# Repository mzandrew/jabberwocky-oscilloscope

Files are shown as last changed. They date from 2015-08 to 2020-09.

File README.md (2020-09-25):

# jabberwocky-oscilloscope
an open-source & open-hardware oscilloscope

Jabberwocky is an acronym for Just Another Big Bandwidth Event Recorder With Oscilloscope Capabilities.

It is a combination of hardware designs and software that uses an ASIC switched-capacitor-array ADC to make a handheld, battery/usb powered, 2 channel oscilloscope with an OLED display.

Development on the oscilloscope was started in January, 2008. A design was finalized and a board was fabricated in May of that year.

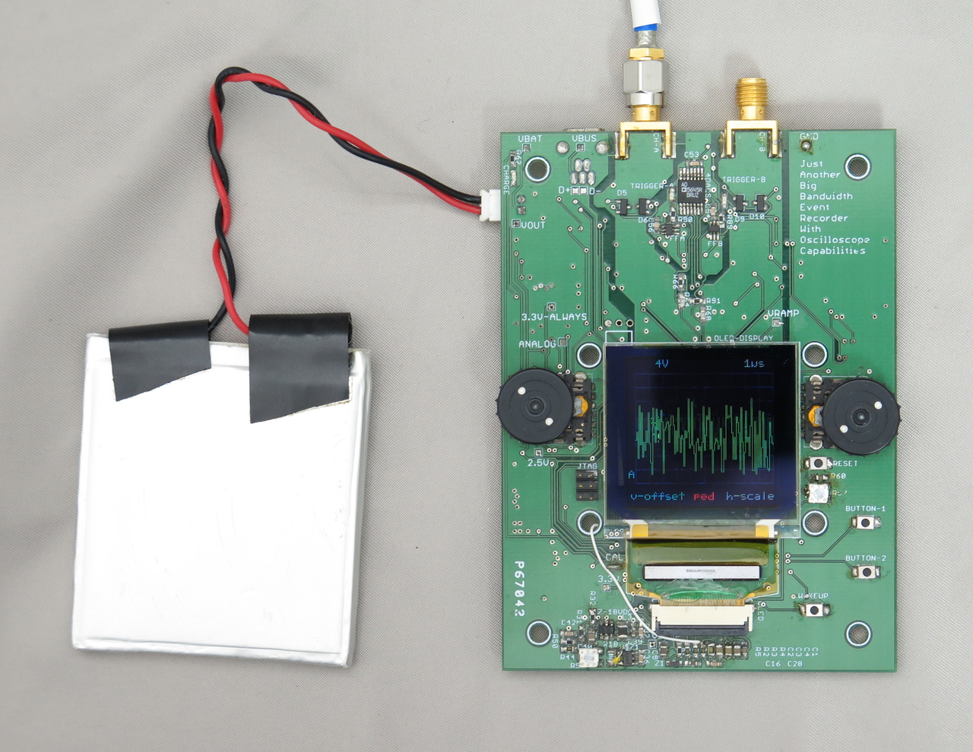
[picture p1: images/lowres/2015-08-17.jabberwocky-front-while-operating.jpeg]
while operating


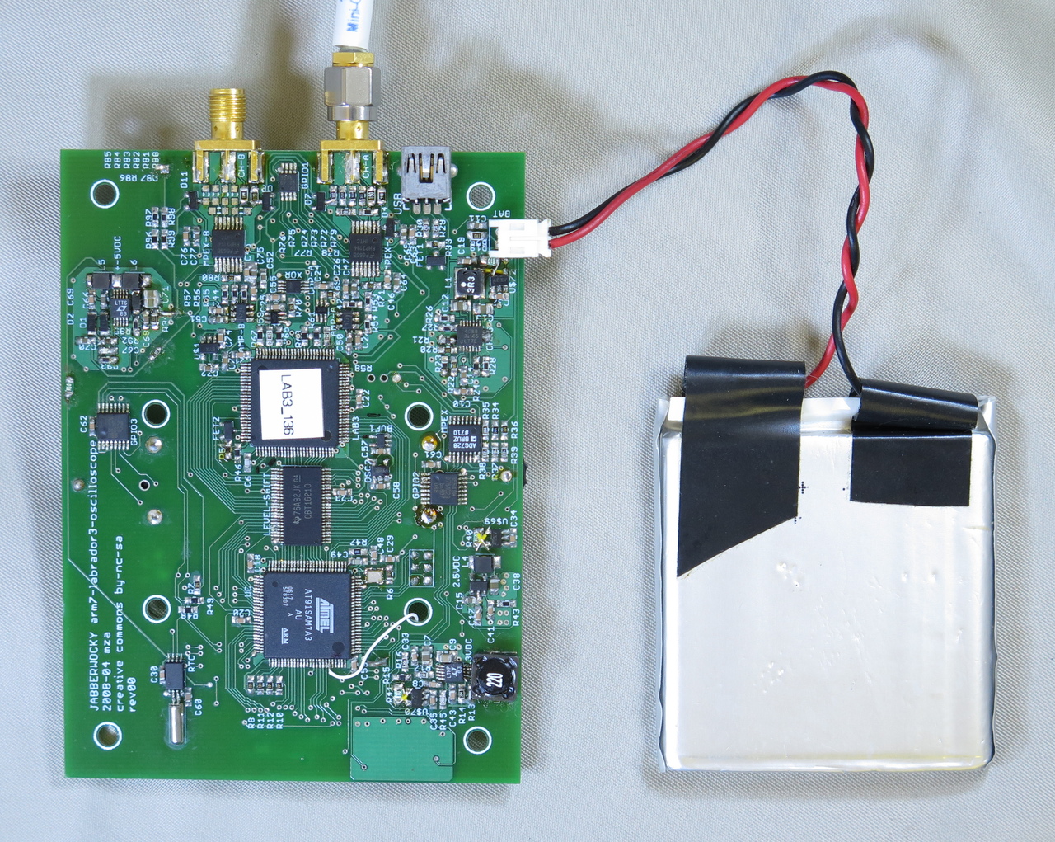
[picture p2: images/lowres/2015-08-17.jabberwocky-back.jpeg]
printed-circuit-board


# overview

The oscilloscope is battery (rechargable LiPoly) or usb powered, has 2 channels of input (DC coupled only), has a 128×124 pixel full-color OLED display. It supports (slightly) advanced triggering or an optional trigger-delay.

The input impedance of this scope is 1MOhm. The analog bandwidth is unknown at this point (and will be until the project is nearly complete). The lab3 can sample billions of times per second, but this oscilloscope will probably only be useful at a much much lower sampling speed. This is due to the choice of input amplifier and multiplexer: The multiplexer has a bandwidth of about 700MHz as does the voltage-feedback operational amplifier.

# files

[PCB schmatic](jabberwocky-PCB-eagle/jabberwocky.schematic.pdf)

[PCB layout](jabberwocky-PCB-eagle/jabberwocky.layout.pdf)

[PCB gerber files](jabberwocky-PCB-eagle/arm7-oscilloscope-gerbers.zip)

# notes

Automatically exported from code.google.com/p/jabberwocky-oscilloscope

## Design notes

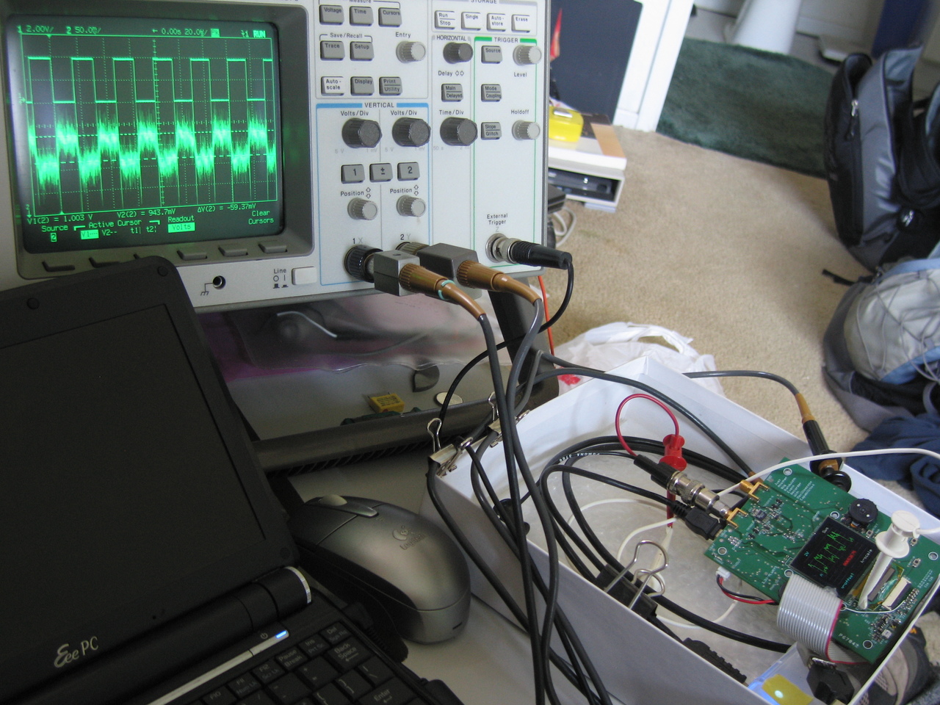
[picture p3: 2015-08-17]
images/lowres/2009-06-07.18_14_17.canon-s70.00828.first-light.second-jabberwocky-scope-trace.jpeg

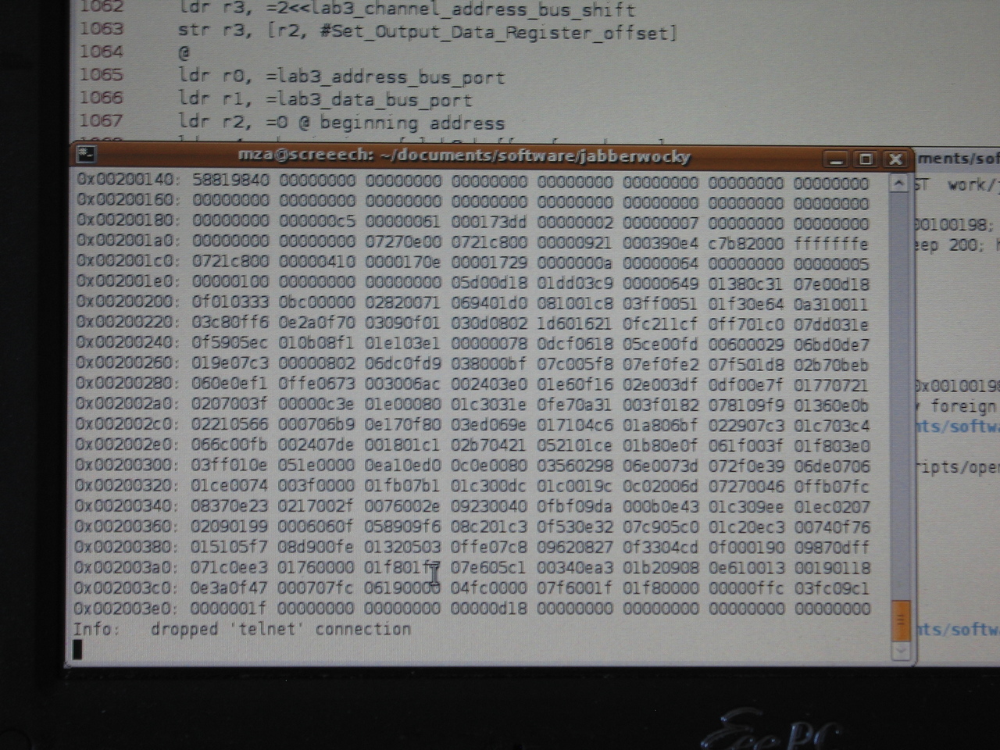
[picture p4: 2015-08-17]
images/lowres/2009-05-30.16_30_52.canon-s70.00823.first-light.first-jabberwocky-lab3-data-hexdump.jpeg

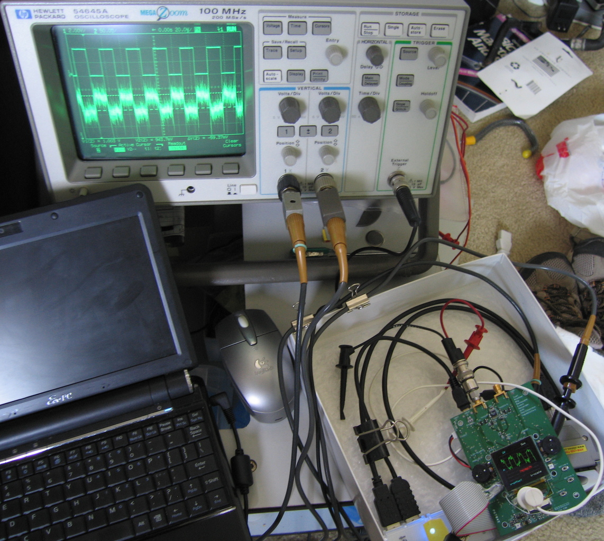
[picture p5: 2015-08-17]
images/lowres/2009-06-07.18_14_04.canon-s70.00827.first-light.first-jabberwocky-scope-trace.jpeg

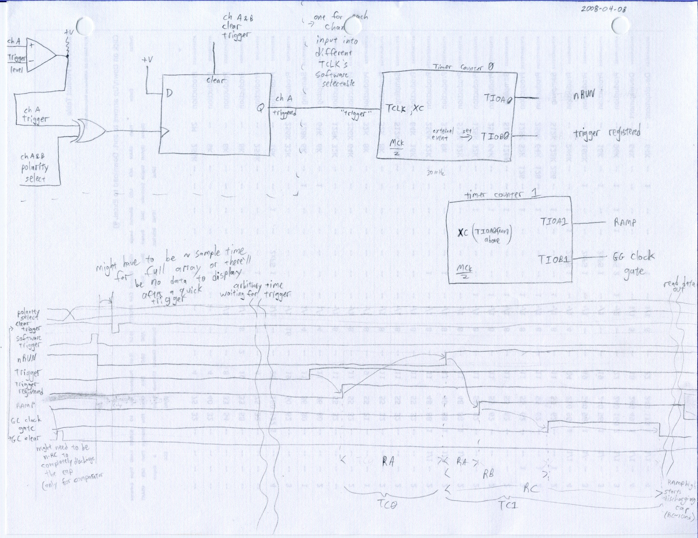
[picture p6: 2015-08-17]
images/jabberwocky-trigger-delay-timing-diagram.jpeg

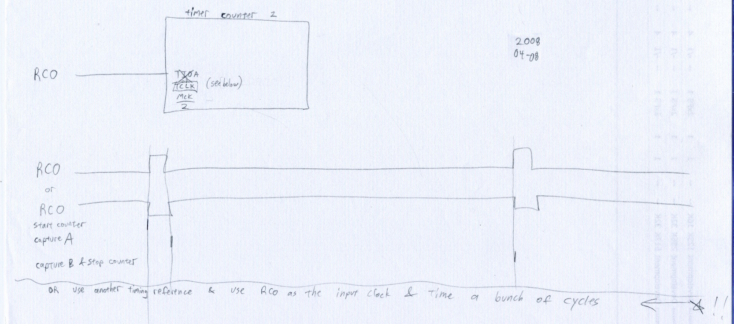
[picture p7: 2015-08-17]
images/jabberwocky-rco-timing-diagram.jpeg

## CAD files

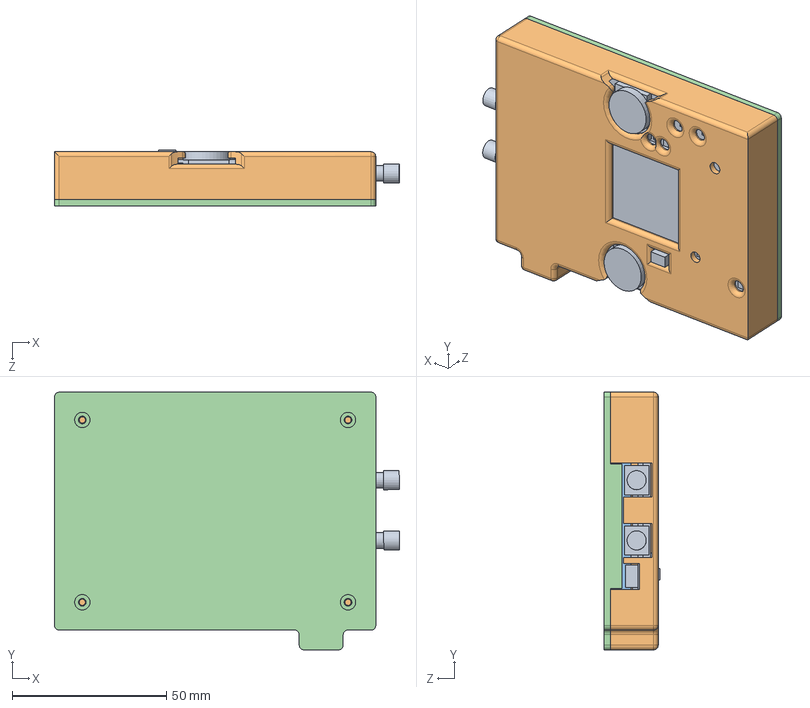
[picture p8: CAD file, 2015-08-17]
jabberwocky-PCB-eagle/jabberwocky.SLDASM
111.7 x 83.4 x 18.0 mm
jabberwocky-PCB
jabberwocky-case-OLED-side
battery
jabberwocky-case-IC-side

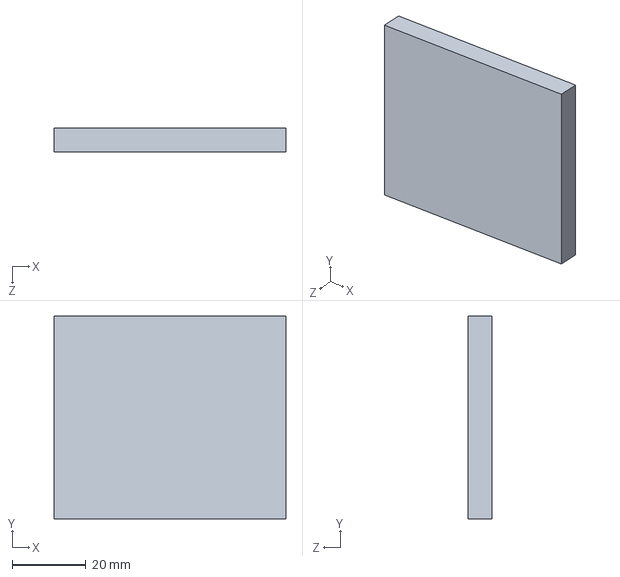
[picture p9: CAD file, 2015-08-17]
jabberwocky-PCB-eagle/battery.SLDPRT
63.0 x 55.0 x 6.50 mm

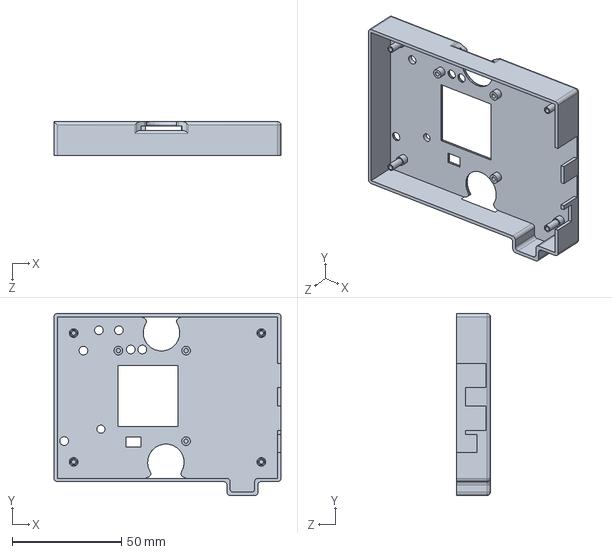
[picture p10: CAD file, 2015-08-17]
jabberwocky-PCB-eagle/jabberwocky-case-OLED-side.sldprt
104.0 x 83.4 x 15.5 mm

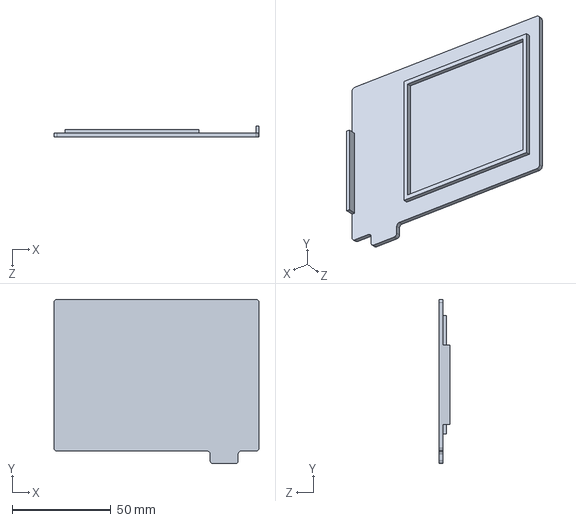
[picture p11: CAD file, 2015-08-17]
jabberwocky-PCB-eagle/jabberwocky-case-IC-side.sldprt
104.0 x 83.4 x 5.75 mm

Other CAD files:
jabberwocky-PCB-eagle/jabberwocky-case-IC-side.STL
jabberwocky-PCB-eagle/jabberwocky-case-OLED-side.STL

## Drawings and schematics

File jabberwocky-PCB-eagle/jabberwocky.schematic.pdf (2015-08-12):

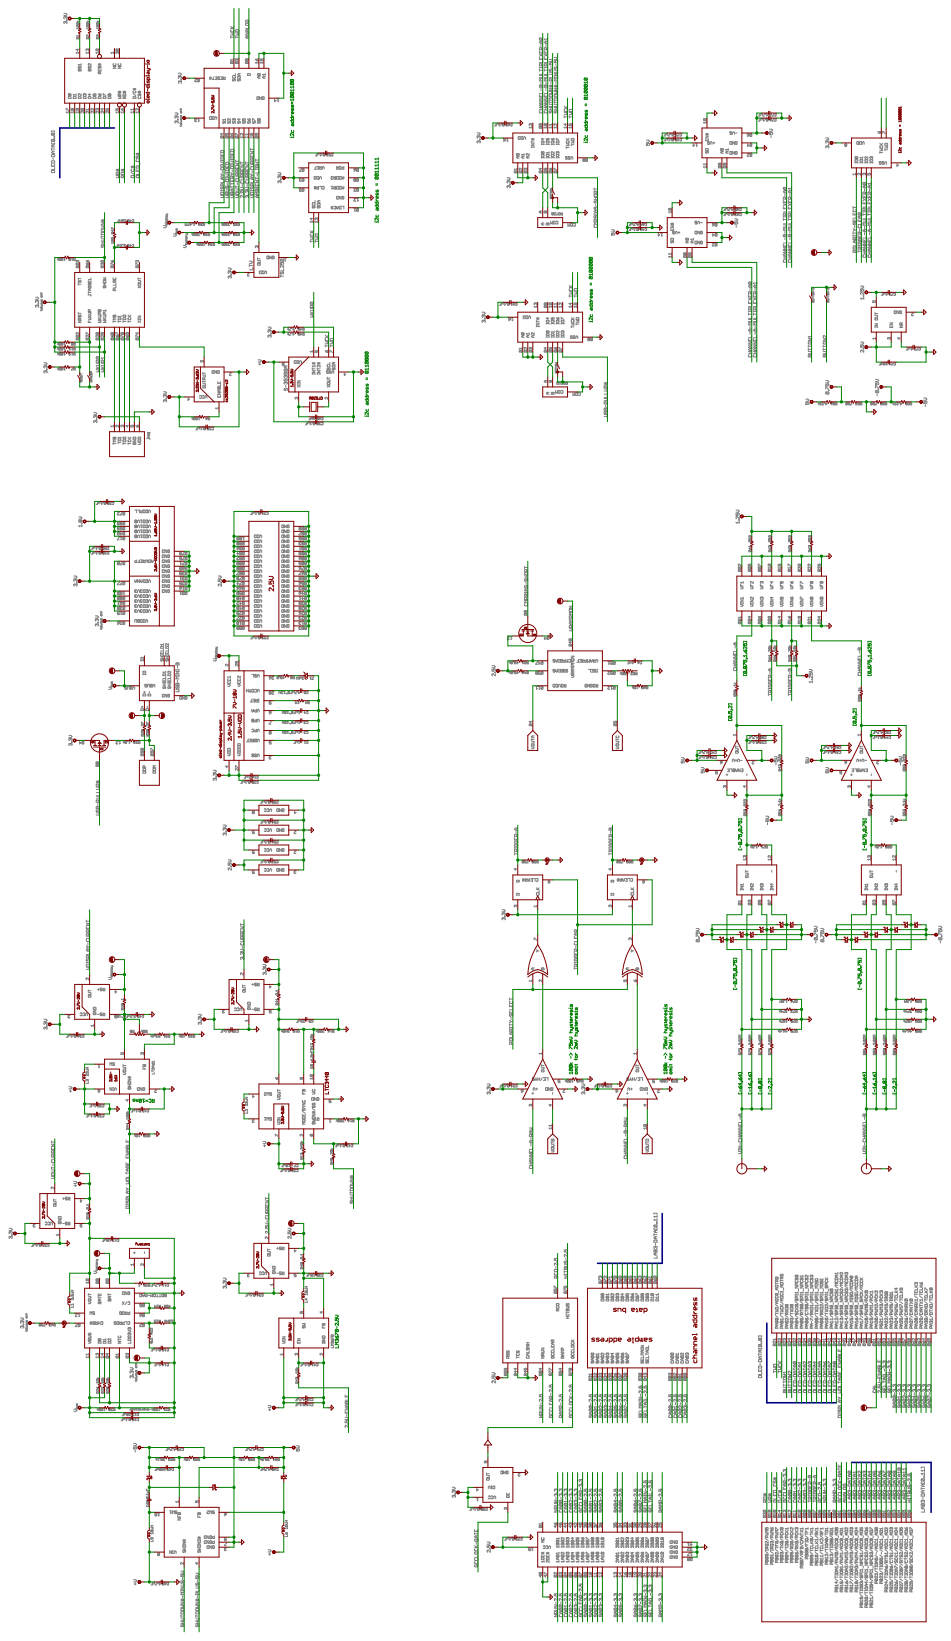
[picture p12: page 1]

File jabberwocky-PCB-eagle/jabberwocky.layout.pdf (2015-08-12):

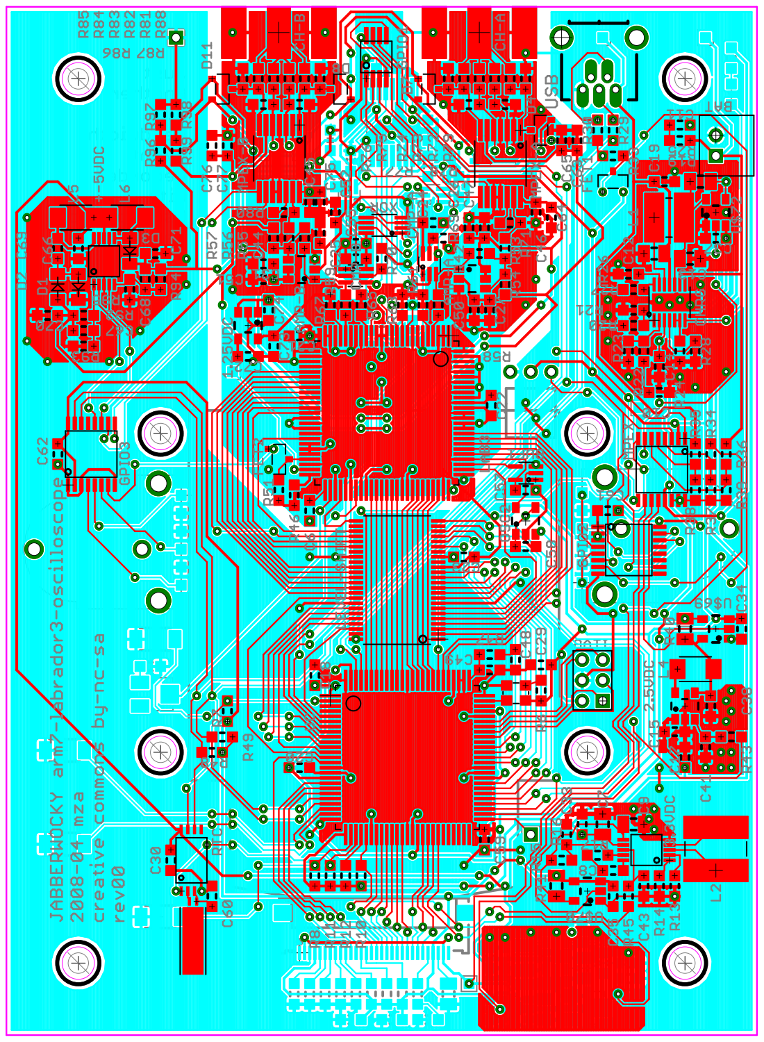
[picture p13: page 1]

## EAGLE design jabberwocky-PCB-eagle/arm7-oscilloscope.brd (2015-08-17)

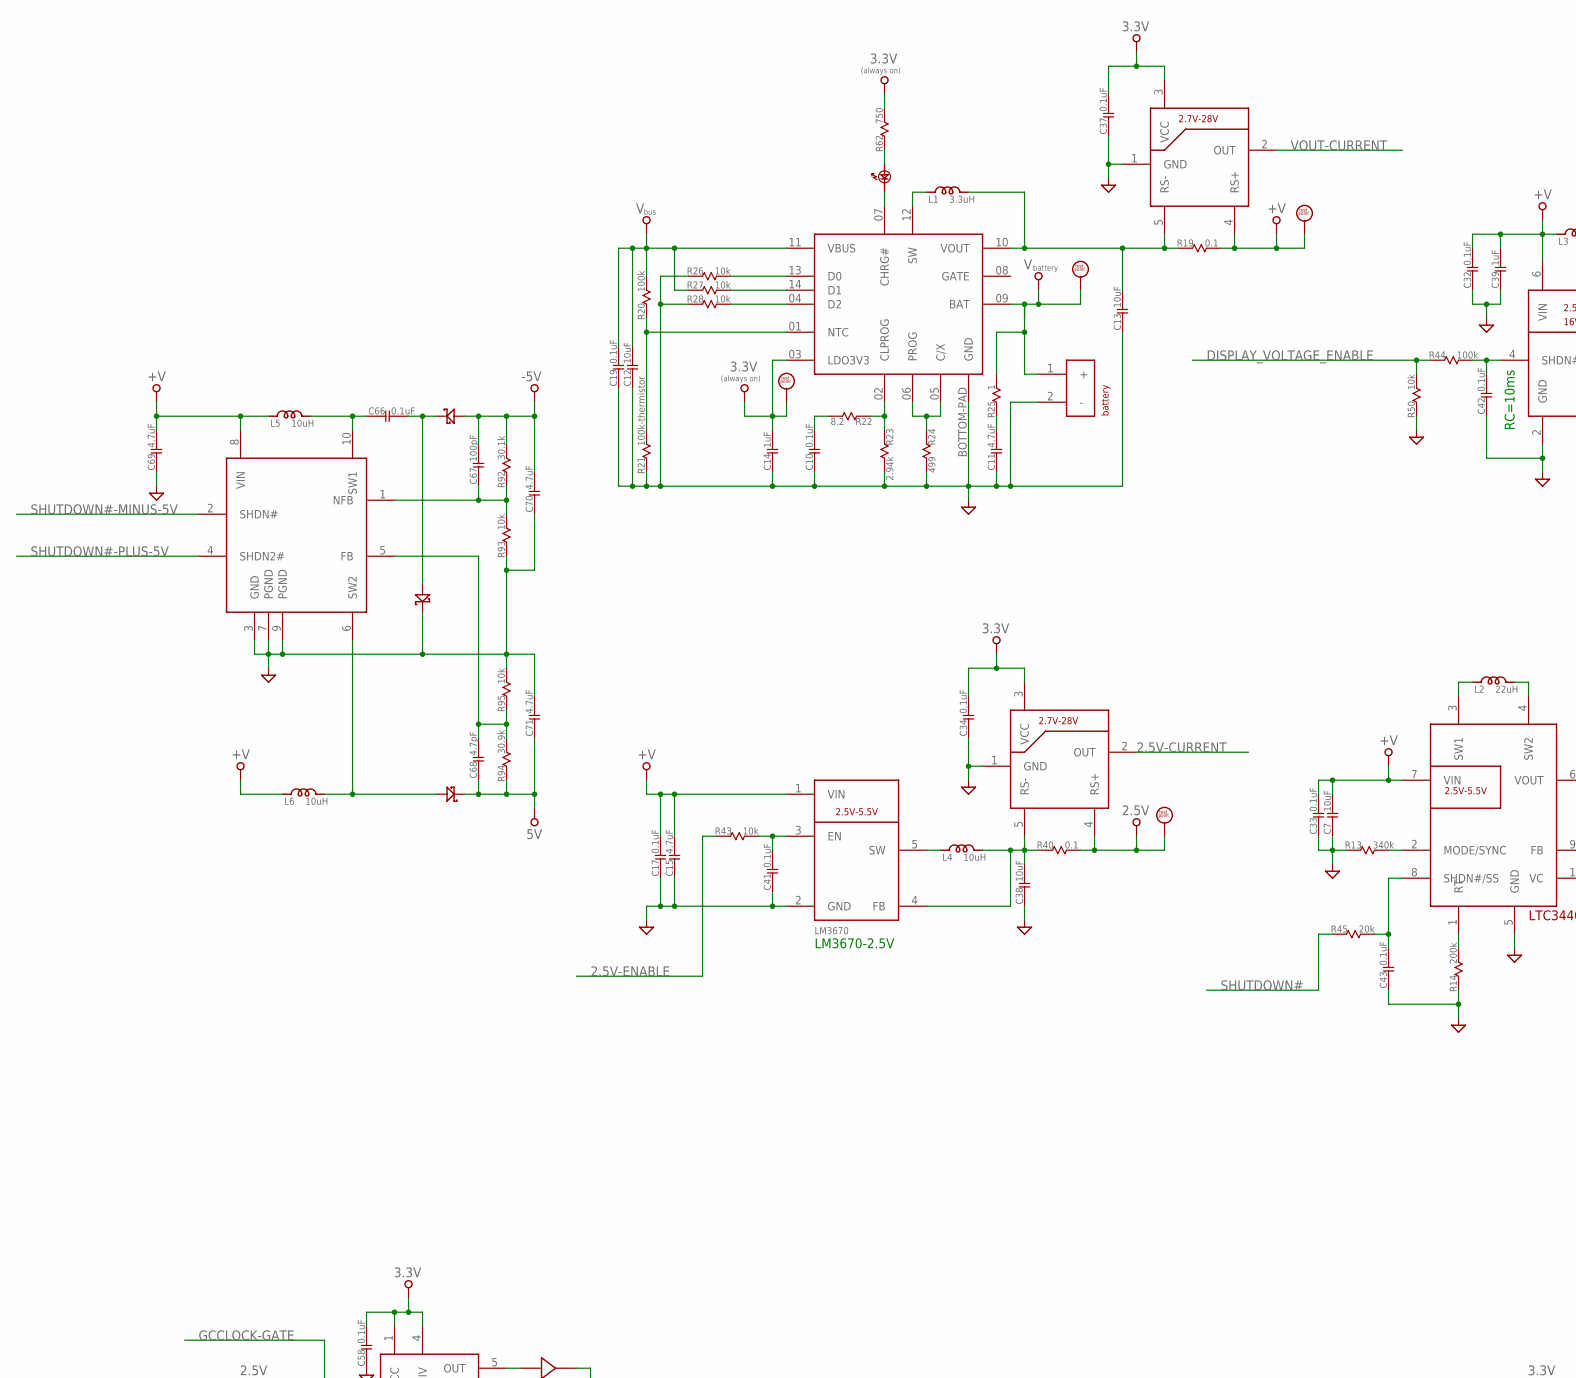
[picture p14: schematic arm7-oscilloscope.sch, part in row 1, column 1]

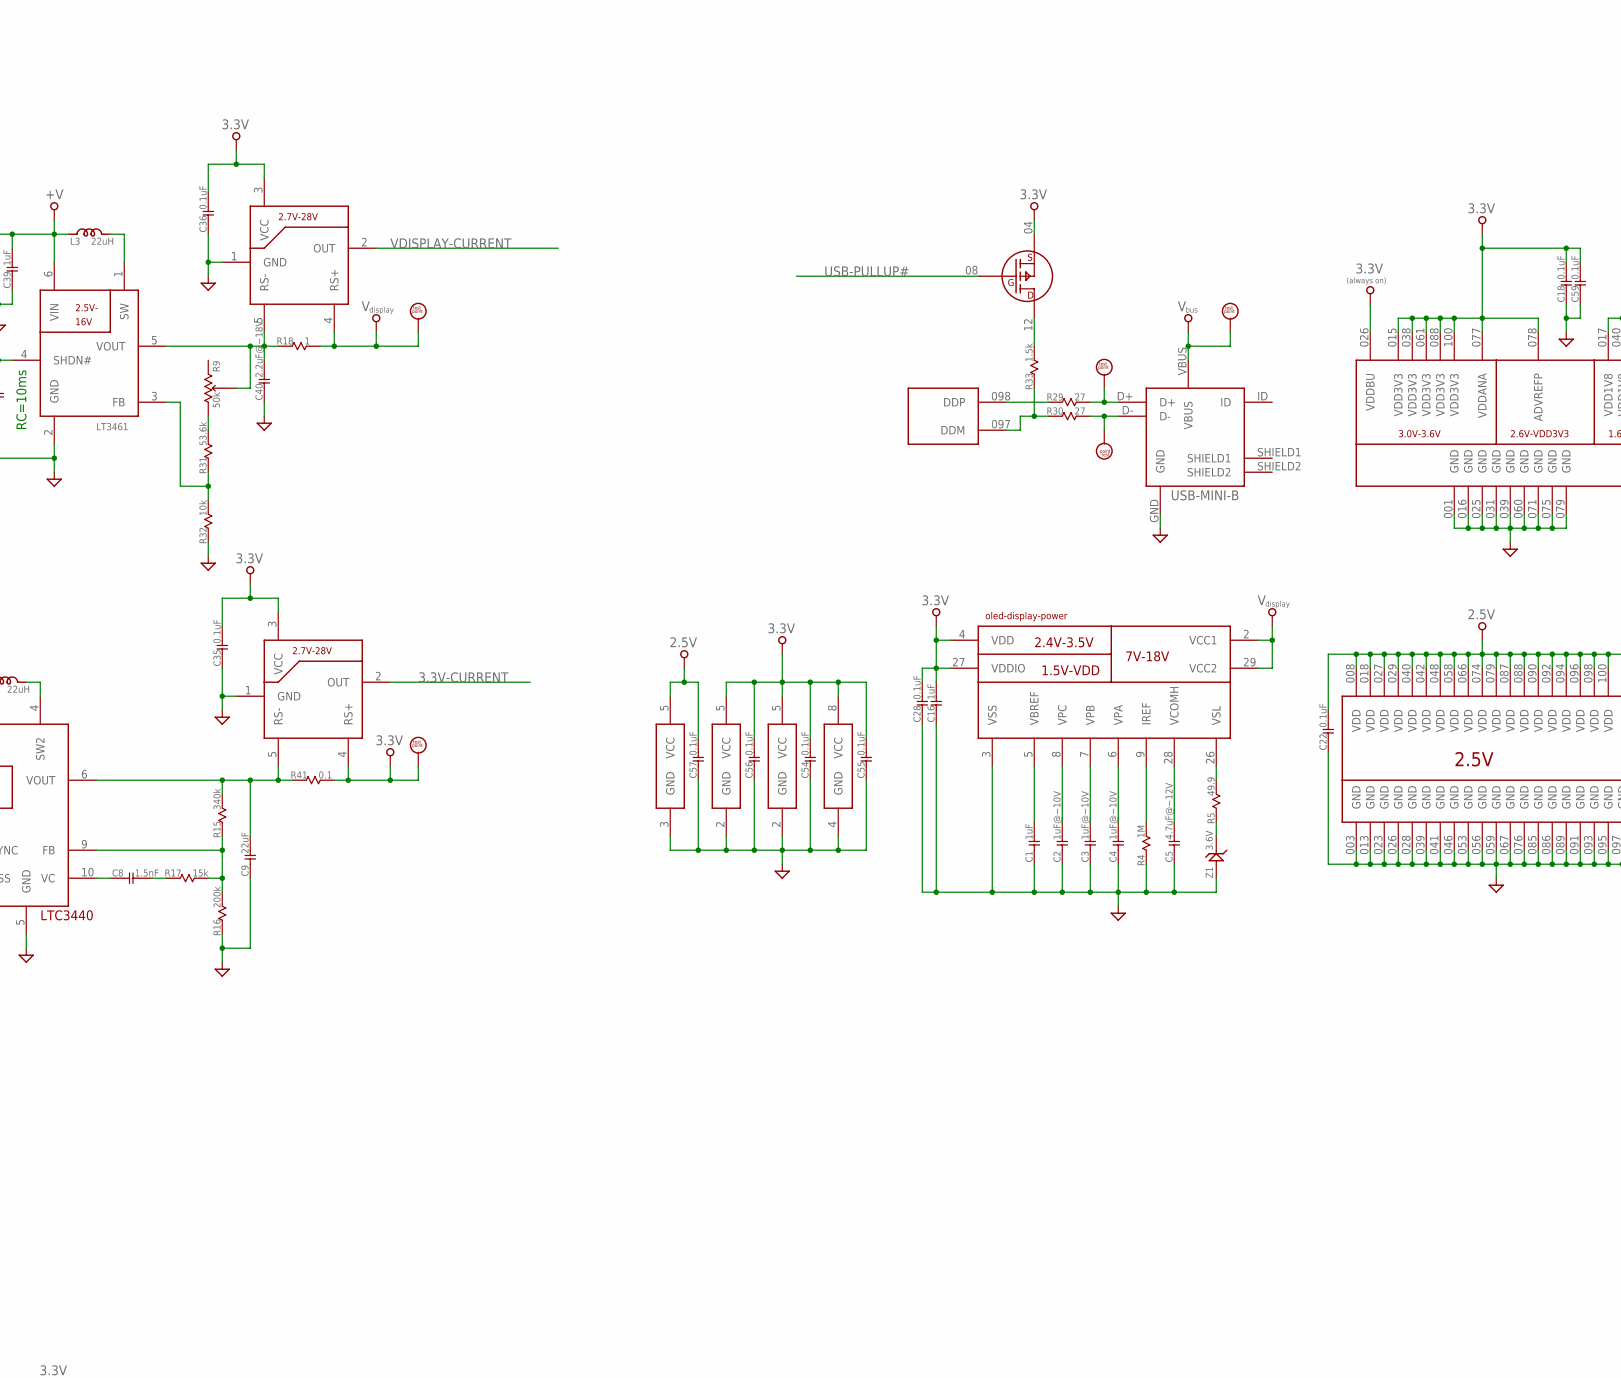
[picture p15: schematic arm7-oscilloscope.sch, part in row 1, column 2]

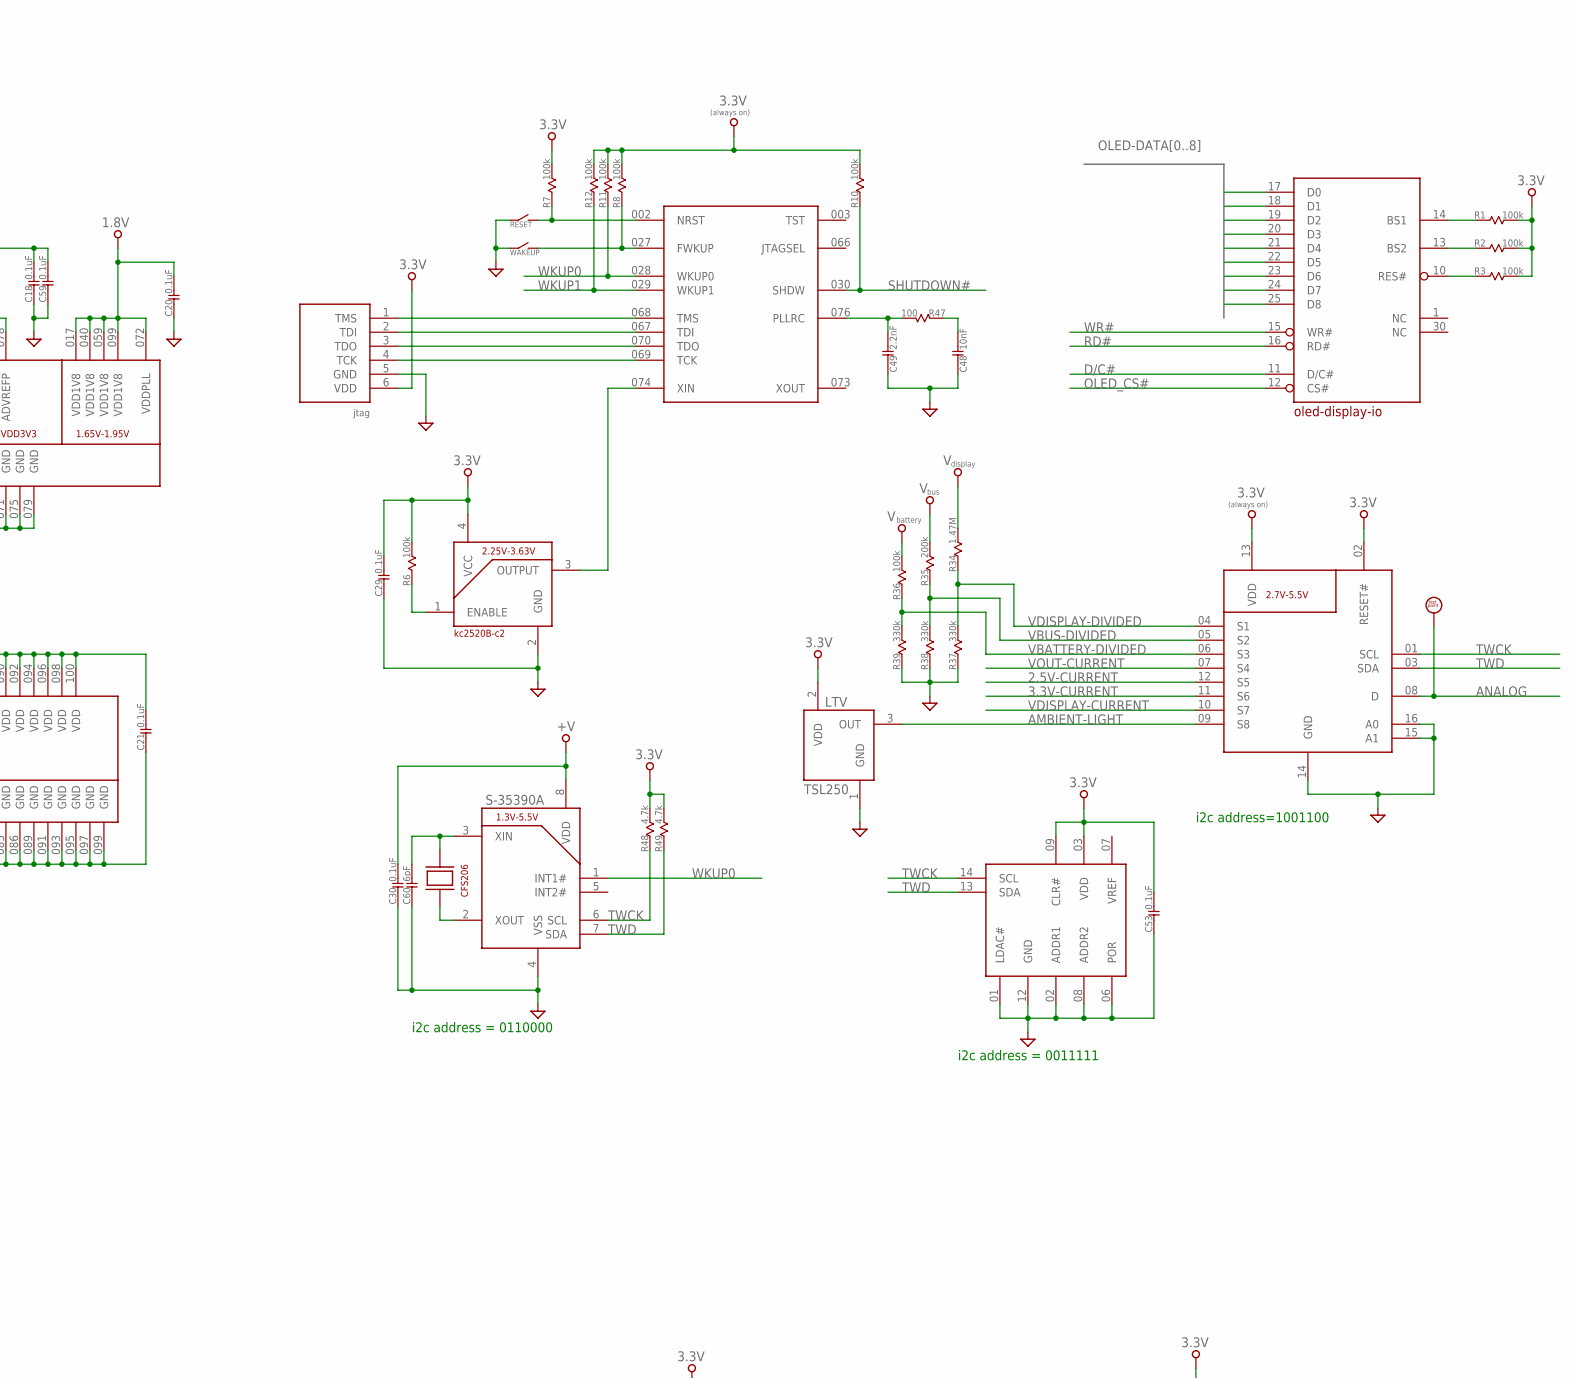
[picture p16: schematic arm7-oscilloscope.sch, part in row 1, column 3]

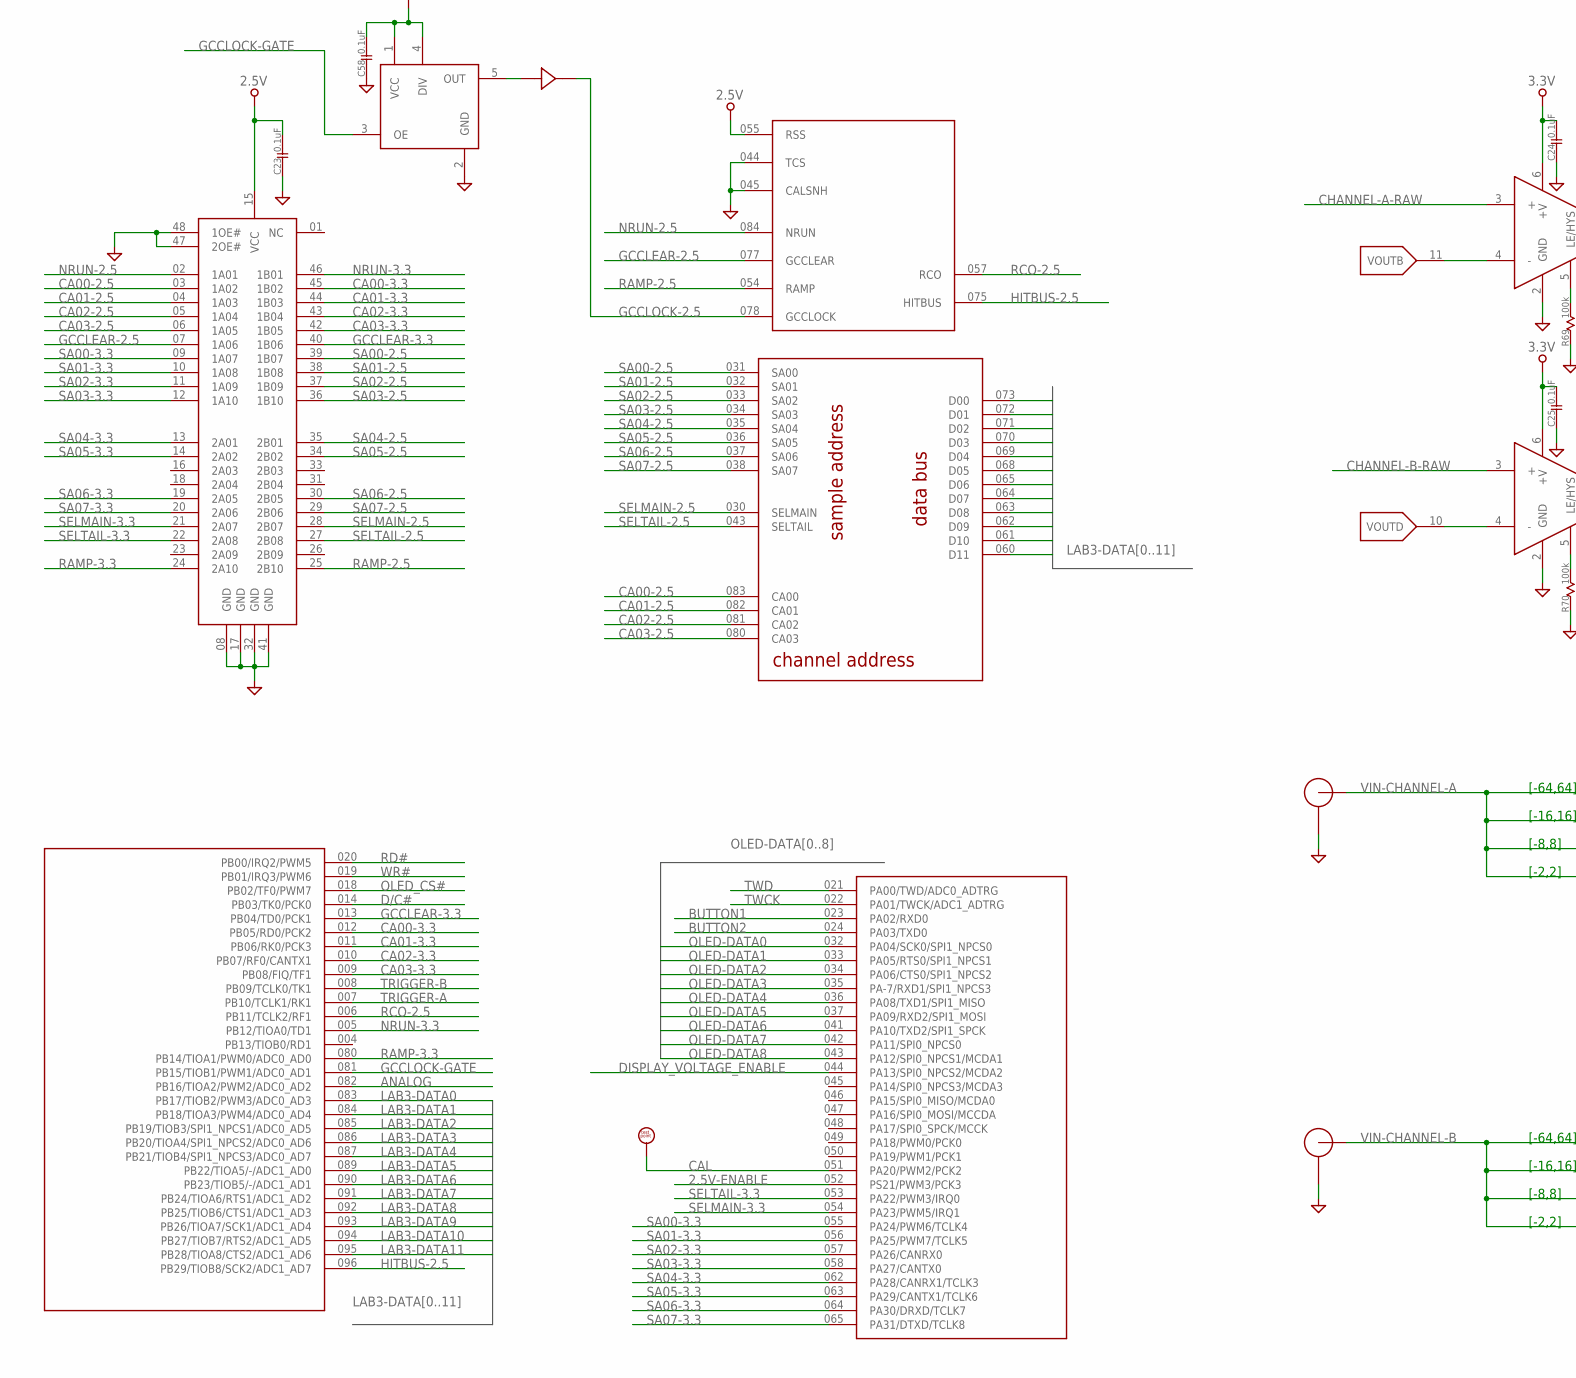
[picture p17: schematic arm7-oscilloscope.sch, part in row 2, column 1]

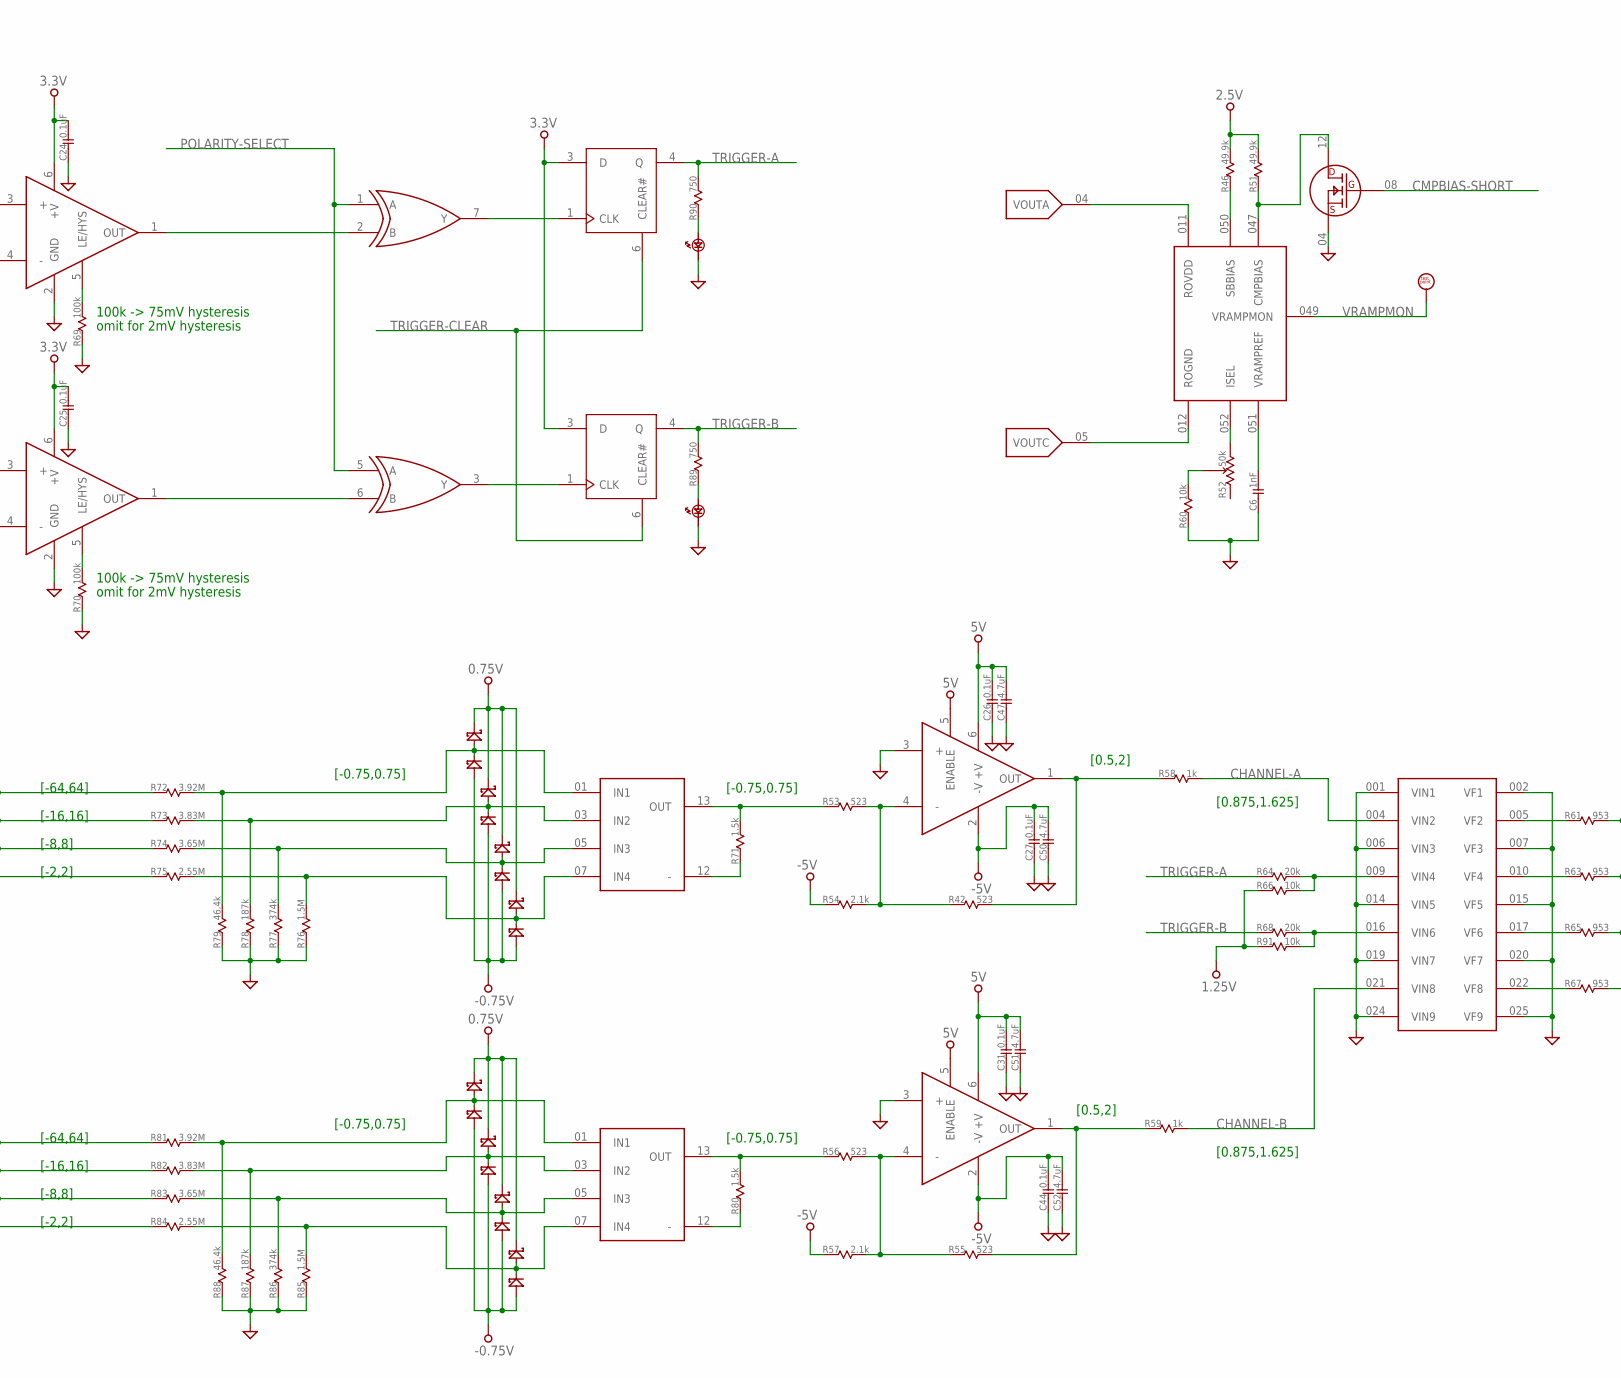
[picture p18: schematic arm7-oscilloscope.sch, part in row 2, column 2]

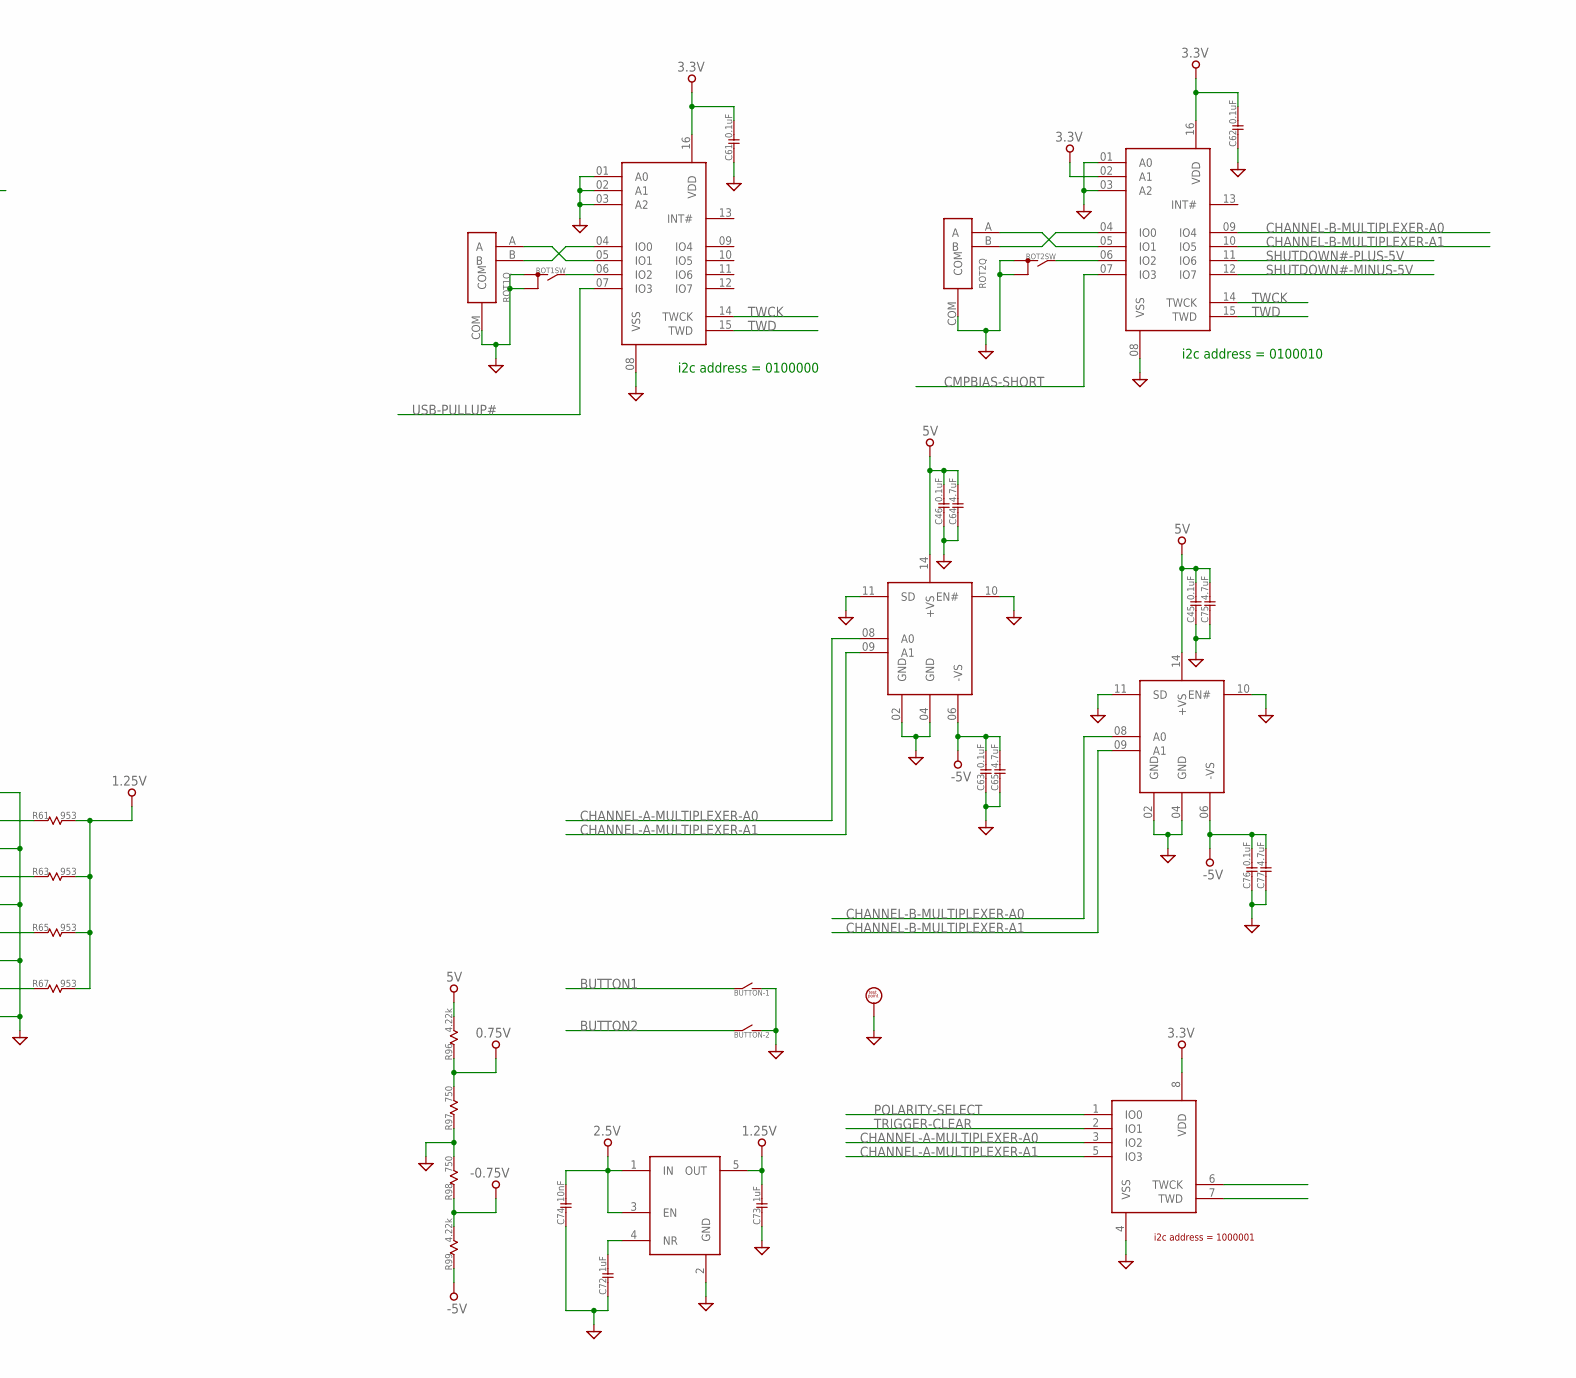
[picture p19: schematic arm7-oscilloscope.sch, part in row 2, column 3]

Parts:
1.25VDC: TPS731XX; SOT-23-5
2.5V, 3.3V, 3.3V-ALWAYS: TEST-POINTSURFACE-MOUNT-1X1; TEST-POINT-SURFACE-MOUNT-1X1
2.5VDC: LM3670; SOT-23-5
3.3VDC: LTC3440; MSOP-10
4DACS: AD56X5R; TSSOP-14
7-18VDC: LT3461; SOT-23-6
+-5VDC: LT1945; MSOP-10
AMP-A: OP-AMP-SOT-23-6; SOT-23-6
AMP-B: OP-AMP-SOT-23-6; SOT-23-6
ANALOG: TEST-POINTSURFACE-MOUNT-1X1; TEST-POINT-SURFACE-MOUNT-1X1
BAT: BATTERY-ON-EXTERNAL-CONNECTOR; S2B-PH-K
BUF1: SN74LVC1G34; SC-70-5
BUTTON-1, BUTTON-2: B3U-1000P
C1, C14, C16, C39, C72, C73: 1uF; 0603
C2, C3, C4: 1uF@~10V; 0603
C5: 4.7uF@~12V; 0805
C6: 1nF; 0603
C7, C12, C13: 10uF; 0805
C8: 1.5nF; 0603
C9: 22uF; 0805
C10, C17, C18, C19, C20, C21, C22, C23, C24, C25, C26, C27, C28, C29, C30, C31, C32, C33, C34, C35, C36, C37, C41, C42, C43, C44, C45, C46, C53, C54, C55, C56, C57, C58, C59, C61, C62, C63, C66, C76: 0.1uF; 0603
C11, C15, C47, C50, C51, C52, C64, C65, C69, C70, C71, C75, C77: 4.7uF; 0603
C38: 10uF; 0603
C40: 2.2uF@~18V; 0805
C48, C74: 10nF; 0603
C49: 2.2nF; 0603
C60: 6pF; 0603
C67: 100pF; 0603
C68: 4.7pF; 0603
CAL: TEST-POINTTHROUGH-HOLE; TEST-POINT-THROUGH-HOLE
CH-A: SMA-SHORT-BARREL-SD-73251-115
CH-B: SMA-SHORT-BARREL-SD-73251-115
CHARGE: LED; 0603
CHRG: LTC4088; DFN-14
CMP-A: ADCMP601; SC-70-6
CMP-B: ADCMP601; SC-70-6
D1, D2, D3: DIODE-SCHOTTKY1005; 1005-DIODE-SCHOTTKY
D4, D5, D6, D7, D8, D9, D10, D11: DIODE-SCHOTTKY-PAIR-ANODE-TO-CATHODE; SOT-23
D+: TEST-POINTSURFACE-MOUNT-1X1; TEST-POINT-SURFACE-MOUNT-1X1
D-: TEST-POINTSURFACE-MOUNT-1X1; TEST-POINT-SURFACE-MOUNT-1X1
FET1: NDS332P; SOT-23
FET2: NDS331N; SOT-23
FFA: 74LVC1G175; SC-70-6
FFB: 74LVC1G175; SC-70-6
GND: TEST-POINTTHROUGH-HOLE; TEST-POINT-THROUGH-HOLE
GPIO1: PCA9536; MSOP-8-OR-TSSOP-8
GPIO2, GPIO3: PCA9554; TSSOP-16
JTAG: HEADER-2MM-2X3-JTAG; HEADER-2MM-2X3
L1: 3.3uH; ELL4-M
L2: 22uH; SD6030
L3: 22uH; 1007
L4, L5, L6: 10uH; 1210
LAB3: LABRADOR3; LQFP-100
LEVEL-SHIFT: SN74CB3T16210; TSSOP-48
LTV: TLS250-BENT; TSL250-BENT
MPEX: ADG728; TSSOP-16
MPEX-A: FHP3194; TSSOP-14
MPEX-B: FHP3194; TSSOP-14
OLED: OLED-DISPLAY-CONNECTOR-2TOP-CONTACTS-IN-USE; XF2M-3015-1A-TOP-CONTACTS-IN-USE
OSC1: KC2520B-C2; OSCILLATOR-2.5X2.0
OSC2: LTC6905; SOT-23-5
R1, R2, R3, R6, R7, R8, R10, R11, R12, R20, R36, R44, R69, R70: 100k; 0603
R4: 1M; 0603
R5: 49.9; 0603
R9, R52: 50k; 3313J-1
R13, R15: 340k; 0603
R14, R16, R35: 200k; 0603
R17: 15k; 0603
R18: 1; 0805
R19, R40, R41: 0.1; 0805
R21: 100k-thermistor; 0603
R22: 8.2; 0603
R23: 2.94k; 0603
R24: 499; 0603
R25: 1; 0603
R26, R27, R28, R32, R43, R50, R60, R66, R91, R93, R95: 10k; 0603
R29, R30: 27; 0603
R31: 53.6k; 0603
R33, R71, R80: 1.5k; 0603
R34: 1.47M; 0603
R37, R38, R39: 330k; 0603
R42, R53, R55, R56: 523; 0603
R45, R64, R68: 20k; 0603
R46, R51: 49.9k; 0603
R47: 100; 0603
R48, R49: 4.7k; 0603
R54, R57: 2.1k; 0603
R58, R59: 1k; 0603
R61, R63, R65, R67: 953; 0603
R62, R89, R90, R97, R98: 750; 0603
R72, R81: 3.92M; 0603
R73, R82: 3.83M; 0603
R74, R83: 3.65M; 0603
R75, R84: 2.55M; 0603
R76, R85: 1.5M; 0603
R77, R86: 374k; 0603
R78, R87: 187k; 0603
R79, R88: 46.4k; 0603
R92: 30.1k; 0603
R94: 30.9k; 0603
R96, R99: 4.22k; 0603
RESET: B3U-1000P
ROT1, ROT2: EVQWK4
RTC: S-35390A; TSSOP-8
TRIGGER-A: LED; 0603
TRIGGER-B: LED; 0603
U$41: CFS206
U$69, U$70, U$71, U$72: MAX4372; SOT-23-5
UC: AT91SAM7A3; LQFP-100
USB: USB-MINI-B; USB-MINI-B-THROUGH-HOLE
VBAT: TEST-POINTSURFACE-MOUNT-1X1; TEST-POINT-SURFACE-MOUNT-1X1
VBUS: TEST-POINTSURFACE-MOUNT-1X1; TEST-POINT-SURFACE-MOUNT-1X1
VDISP: TEST-POINTSURFACE-MOUNT-1X1; TEST-POINT-SURFACE-MOUNT-1X1
VOUT: TEST-POINTSURFACE-MOUNT-1X1; TEST-POINT-SURFACE-MOUNT-1X1
VRAMP: TEST-POINTSURFACE-MOUNT-1X1; TEST-POINT-SURFACE-MOUNT-1X1
WAKEUP: B3U-1000P
XOR: 74LVC2G86; VSSOP-8
Z1: 3.6V; 0603

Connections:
0.75V: D4.04 (CATHODE), D5.04 (CATHODE), D6.04 (CATHODE), D7.04 (CATHODE), D8.04 (CATHODE), D9.04 (CATHODE), D10.04 (CATHODE), D11.04 (CATHODE), R96.1, R97.2
1.8V: C20.2, UC.017 (VDD1V8), UC.040 (VDD1V8), UC.059 (VDD1V8), UC.072 (VDDPLL), UC.099 (VDD1V8)
1.25V: 1.25VDC.5 (OUT), C73.2, R61.2, R63.2, R65.2, R66.1, R67.2, R91.1
2.5V: 1.25VDC.1 (IN), 1.25VDC.3 (EN), 2.5V.1, BUF1.5 (VCC), C21.2, C22.2, C23.2, C57.2, C74.2, LAB3.008 (VDD), LAB3.018 (VDD), LAB3.027 (VDD), LAB3.029 (VDD), LAB3.040 (VDD), LAB3.042 (VDD), LAB3.048 (VDD), LAB3.055 (RSS), LAB3.058 (VDD), LAB3.066 (VDD), LAB3.074 (VDD), LAB3.079 (VDD), LAB3.087 (VDD), LAB3.088 (VDD), LAB3.090 (VDD), LAB3.092 (VDD), LAB3.094 (VDD), LAB3.096 (VDD), LAB3.098 (VDD), LAB3.100 (VDD), LEVEL-SHIFT.15 (VCC), R40.2, R46.2, R51.2, U$69.4 (RS+)
2.5V-CURRENT: MPEX.12 (S5), U$69.2 (OUT)
2.5V-ENABLE: R43.1, UC.052 (PS21/PWM3/PCK3)
3.3V: 3.3V.1, 4DACS.03 (VDD), 4DACS.09 (CLR#), C16.2, C18.2, C24.2, C25.2, C28.2, C29.2, C34.2, C35.2, C36.2, C37.2, C53.2, C54.2, C55.2, C56.2, C58.2, C59.2, C61.2, C62.2, CMP-A.6 (+V), CMP-B.6 (+V), FET1.04 (S), FFA.3 (D), FFA.5 (VCC), FFB.3 (D), FFB.5 (VCC), GPIO1.8 (VDD), GPIO2.16 (VDD), GPIO3.02 (A1), GPIO3.16 (VDD), JTAG.6 (VDD), LTV.2 (VDD), MPEX.02 (RESET#), OLED.4 (VDD), OLED.27 (VDDIO), OSC1.4 (VCC), OSC2.1 (VCC), OSC2.4 (DIV), R1.2, R2.2, R3.2, R6.2, R7.2, R41.2, R48.2, R49.2, U$69.3 (VCC), U$70.3 (VCC), U$70.4 (RS+), U$71.3 (VCC), U$72.3 (VCC), UC.015 (VDD3V3), UC.038 (VDD3V3), UC.061 (VDD3V3), UC.077 (VDDANA), UC.078 (ADVREFP), UC.088 (VDD3V3), UC.100 (VDD3V3), XOR.8 (VCC)
3.3V-ALWAYS: 3.3V-ALWAYS.1, C14.2, CHRG.03 (LDO3V3), MPEX.13 (VDD), R8.2, R10.2, R11.2, R12.2, R62.2, UC.026 (VDDBU)
3.3V-CURRENT: MPEX.11 (S6), U$70.2 (OUT)
5V: AMP-A.5 (ENABLE), AMP-A.6 (+V), AMP-B.5 (ENABLE), AMP-B.6 (+V), C26.2, C31.2, C45.2, C46.2, C47.2, C51.2, C64.2, C68.1, C71.1, C75.2, D3.P$2 (CATHODE), MPEX-A.14 (+VS), MPEX-B.14 (+VS), R94.1, R96.2
+V: 2.5VDC.1 (VIN), 3.3VDC.7 (VIN), 7-18VDC.6 (VIN), +-5VDC.8 (VIN), C7.2, C15.2, C17.2, C30.2, C32.2, C33.2, C39.2, C69.2, L3.1, L5.1, L6.1, R19.2, RTC.8 (VDD), U$72.4 (RS+), VOUT.1
-0.75V: D4.08 (ANODE), D5.08 (ANODE), D6.08 (ANODE), D7.08 (ANODE), D8.08 (ANODE), D9.08 (ANODE), D10.08 (ANODE), D11.08 (ANODE), R98.1, R99.2
-5V: AMP-A.2 (-V), AMP-B.2 (-V), C27.2, C44.2, C50.2, C52.2, C63.2, C65.2, C67.2, C70.2, C76.2, C77.2, D1.P$1 (ANODE), MPEX-A.06 (-VS), MPEX-B.06 (-VS), R54.1, R57.1, R92.2, R99.1
AMBIENT-LIGHT: LTV.3 (OUT), MPEX.09 (S8)
ANALOG: ANALOG.1, MPEX.08 (D), UC.082 (PB16/TIOA2/PWM2/ADC0_AD2)
BUTTON1: BUTTON-1.1, UC.023 (PA02/RXD0)
BUTTON2: BUTTON-2.1, UC.024 (PA03/TXD0)
CA00-2.5: LAB3.083 (CA00), LEVEL-SHIFT.03 (1A02)
CA00-3.3: LEVEL-SHIFT.45 (1B02), UC.012 (PB05/RD0/PCK2)
CA01-2.5: LAB3.082 (CA01), LEVEL-SHIFT.04 (1A03)
CA01-3.3: LEVEL-SHIFT.44 (1B03), UC.011 (PB06/RK0/PCK3)
CA02-2.5: LAB3.081 (CA02), LEVEL-SHIFT.05 (1A04)
CA02-3.3: LEVEL-SHIFT.43 (1B04), UC.010 (PB07/RF0/CANTX1)
CA03-2.5: LAB3.080 (CA03), LEVEL-SHIFT.06 (1A05)
CA03-3.3: LEVEL-SHIFT.42 (1B05), UC.009 (PB08/FIQ/TF1)
CAL: CAL.1, UC.051 (PA20/PWM2/PCK2)
CHANNEL-A: LAB3.004 (VIN2), R58.2
CHANNEL-A-MULTIPLEXER-A0: GPIO1.3 (IO2), MPEX-A.08 (A0)
CHANNEL-A-MULTIPLEXER-A1: GPIO1.5 (IO3), MPEX-A.09 (A1)
CHANNEL-A-RAW: AMP-A.1 (OUT), CMP-A.3 (+), R42.2, R58.1
CHANNEL-B: LAB3.021 (VIN8), R59.2
CHANNEL-B-MULTIPLEXER-A0: GPIO3.09 (IO4), MPEX-B.08 (A0)
CHANNEL-B-MULTIPLEXER-A1: GPIO3.10 (IO5), MPEX-B.09 (A1)
CHANNEL-B-RAW: AMP-B.1 (OUT), CMP-B.3 (+), R55.2, R59.1
CHRG: CHARGE.C, CHRG.07 (CHRG#)
CMPBIAS-SHORT: FET2.08 (G), GPIO3.07 (IO3)
D/C#: OLED.11 (D/C#), UC.014 (PB03/TK0/PCK0)
DISPLAY_VOLTAGE_ENABLE: R44.1, R50.2, UC.044 (PA13/SPI0_NPCS2/MCDA2)
GCCLEAR-2.5: LAB3.077 (GCCLEAR), LEVEL-SHIFT.07 (1A06)
GCCLEAR-3.3: LEVEL-SHIFT.40 (1B06), UC.013 (PB04/TD0/PCK1)
GCCLOCK-2.5: BUF1.4 (OUT), LAB3.078 (GCCLOCK)
GCCLOCK-GATE: OSC2.3 (OE), UC.081 (PB15/TIOB1/PWM1/ADC0_AD1)
GND: 1.25VDC.2 (GND), 2.5VDC.2 (GND), 3.3VDC.5 (GND), 4DACS.01 (LDAC#), 4DACS.02 (ADDR1), 4DACS.06 (POR), 4DACS.08 (ADDR2), 4DACS.12 (GND), 7-18VDC.2 (GND), +-5VDC.3 (GND), +-5VDC.7 (PGND), +-5VDC.9 (PGND), AMP-A.3 (+), AMP-B.3 (+), BAT.2 (-), BUF1.3 (GND), BUTTON-1.2, BUTTON-2.2, C1.1, C2.1, C3.1, C4.1, C5.1, C6.1, C7.1, C9.1, C10.1, C11.1, C12.1, C13.1, C14.1, C15.1, C16.1, C17.1, C18.1, C19.1, C20.1, C21.1, C22.1, C23.1, C24.1, C25.1, C26.1, C27.1, C28.1, C29.1, C30.1, C31.1, C32.1, C33.1, C34.1, C35.1, C36.1, C37.1, C38.1, C39.1, C40.1, C41.1, C42.1, C43.1, C44.1, C45.1, C46.1, C47.1, C48.1, C49.1, C50.1, C51.1, C52.1, C53.1, C54.1, C55.1, C56.1, C57.1, C58.1, C59.1, C60.1, C61.1, C62.1, C63.1, C64.1, C65.1, C69.1, C70.1, C71.2, C72.1, C73.1, C74.1, C75.1, C76.1, C77.1, CH-A.GND@1 (GND), CH-A.GND@2 (GND), CH-A.GND@3 (GND)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
HITBUS-2.5: LAB3.075 (HITBUS), UC.096 (PB29/TIOB8/SCK2/ADC1_AD7)
LAB3-DATA0: LAB3.073 (D00), UC.083 (PB17/TIOB2/PWM3/ADC0_AD3)
LAB3-DATA1: LAB3.072 (D01), UC.084 (PB18/TIOA3/PWM4/ADC0_AD4)
LAB3-DATA2: LAB3.071 (D02), UC.085 (PB19/TIOB3/SPI1_NPCS1/ADC0_AD5)
LAB3-DATA3: LAB3.070 (D03), UC.086 (PB20/TIOA4/SPI1_NPCS2/ADC0_AD6)
LAB3-DATA4: LAB3.069 (D04), UC.087 (PB21/TIOB4/SPI1_NPCS3/ADC0_AD7)
LAB3-DATA5: LAB3.068 (D05), UC.089 (PB22/TIOA5/-/ADC1_AD0)
LAB3-DATA6: LAB3.065 (D06), UC.090 (PB23/TIOB5/-/ADC1_AD1)
LAB3-DATA7: LAB3.064 (D07), UC.091 (PB24/TIOA6/RTS1/ADC1_AD2)
LAB3-DATA8: LAB3.063 (D08), UC.092 (PB25/TIOB6/CTS1/ADC1_AD3)
LAB3-DATA9: LAB3.062 (D09), UC.093 (PB26/TIOA7/SCK1/ADC1_AD4)
LAB3-DATA10: LAB3.061 (D10), UC.094 (PB27/TIOB7/RTS2/ADC1_AD5)
LAB3-DATA11: LAB3.060 (D11), UC.095 (PB28/TIOA8/CTS2/ADC1_AD6)
LTC4088-D0: CHRG.13 (D0), R26.2
LTC4088-D1: CHRG.14 (D1), R27.2
LTC4088-D2: CHRG.04 (D2), R28.2
MAIN_OSCILLATOR: OSC1.3 (OUTPUT), UC.074 (XIN)
unnamed: R7.1, RESET.2, UC.002 (NRST)
unnamed: R8.1, UC.027 (FWKUP), WAKEUP.2
unnamed: +-5VDC.1 (NFB), C67.1, R92.1, R93.2
unnamed: 4DACS.11 (VOUTB), CMP-A.4 (-)
unnamed: R52.1-CCW, R60.2
unnamed: CHARGE.A, R62.1
unnamed: BUF1.2 (IN), OSC2.5 (OUT)
unnamed: OLED.14 (BS1), R1.1
unnamed: 1.25VDC.4 (NR), C72.2
unnamed: LAB3.016 (VIN6), R68.2, R91.2
unnamed: LAB3.009 (VIN4), R64.2, R66.2
unnamed: GPIO2.04 (IO0), ROT1.B
unnamed: GPIO2.05 (IO1), ROT1.A
unnamed: GPIO2.06 (IO2), ROT1.SW2 (1)
unnamed: +-5VDC.5 (FB), C68.2, R94.2, R95.1
unnamed: GPIO3.06 (IO2), ROT2.SW2 (1)
unnamed: GPIO3.04 (IO0), ROT2.B
unnamed: GPIO3.05 (IO1), ROT2.A
unnamed: +-5VDC.6 (SW2), D3.P$1 (ANODE), L6.2
unnamed: 3.3VDC.2 (MODE/SYNC), R13.2
unnamed: 3.3VDC.3 (SW1), L2.1
unnamed: 3.3VDC.1 (RT), R14.2
unnamed: 3.3VDC.4 (SW2), L2.2
unnamed: C8.2, R17.1
unnamed: OLED.13 (BS2), R2.1
unnamed: OLED.10 (RES#), R3.1
unnamed: +-5VDC.10 (SW1), C66.1, L5.2
unnamed: C1.2, OLED.5 (VBREF)
unnamed: C2.2, OLED.8 (VPC)
unnamed: C3.2, OLED.7 (VPB)
unnamed: C4.2, OLED.6 (VPA)
unnamed: OLED.9 (IREF), R4.2
unnamed: C5.2, OLED.28 (VCOMH)
unnamed: OLED.26 (VSL), R5.2
unnamed: R5.1, Z1.2
unnamed: C66.2, D1.P$2 (CATHODE), D2.P$1 (ANODE)
unnamed: 3.3VDC.10 (VC), C8.1
unnamed: OSC1.1 (ENABLE), R6.1
unnamed: FET1.12 (D), R33.2
unnamed: LAB3.052 (ISEL), R52.3-CW
unnamed: 3.3VDC.9 (FB), R15.1, R16.2, R17.2
unnamed: 2.5VDC.4 (FB), C38.2, L4.2, R40.1, U$69.5 (RS-)
unnamed: C60.2, RTC.3 (XIN), U$41.P$1 (1)
unnamed: RTC.2 (XOUT), U$41.P$2 (2)
unnamed: 7-18VDC.1 (SW), L3.2
unnamed: LAB3.050 (SBBIAS), R46.1
unnamed: 7-18VDC.3 (FB), R31.1, R32.2
unnamed: FET2.12 (D), LAB3.047 (CMPBIAS), R51.1
unnamed: C6.2, LAB3.051 (VRAMPREF)
unnamed: 4DACS.04 (VOUTA), LAB3.011 (ROVDD)
unnamed: CHRG.01 (NTC), R20.1, R21.2
unnamed: CHRG.12 (SW), L1.1
unnamed: 4DACS.05 (VOUTC), LAB3.012 (ROGND)
unnamed: C10.2, R22.2
unnamed: CHRG.02 (CLPROG), R22.1, R23.1
unnamed: CHRG.05 (C/X), CHRG.06 (PROG), R24.1
unnamed: C49.2, R47.2, UC.076 (PLLRC)
unnamed: C11.2, R25.1
unnamed: CMP-A.1 (OUT), XOR.2 (B)
unnamed: C48.2, R47.1
unnamed: D+.1, R29.2, USB.D+
unnamed: D-.1, R30.2, USB.D-
unnamed: R29.1, UC.098 (DDP)
unnamed: R30.1, R33.1, UC.097 (DDM)
unnamed: JTAG.1 (TMS), UC.068 (TMS)
unnamed: JTAG.2 (TDI), UC.067 (TDI)
unnamed: JTAG.3 (TDO), UC.070 (TDO)
unnamed: 3.3VDC.6 (VOUT), C9.2, R15.2, R41.1, U$70.5 (RS-)
unnamed: JTAG.4 (TCK), UC.069 (TCK)
unnamed: 2.5VDC.3 (EN), C41.2, R43.2
unnamed: R9.3-CW, R31.2
unnamed: 7-18VDC.4 (SHDN#), C42.2, R44.2
unnamed: 3.3VDC.8 (SHDN#/SS), C43.2, R45.2
unnamed: FFA.1 (CLK), XOR.7 (Y)
unnamed: FFB.1 (CLK), XOR.3 (Y)
unnamed: CMP-B.1 (OUT), XOR.6 (B)
unnamed: AMP-A.4 (-), R42.1, R53.2, R54.2
unnamed: AMP-B.4 (-), R55.1, R56.2, R57.2
unnamed: 4DACS.10 (VOUTD), CMP-B.4 (-)
unnamed: LAB3.005 (VF2), R61.1
unnamed: LAB3.010 (VF4), R63.1
unnamed: LAB3.017 (VF6), R65.1
unnamed: LAB3.022 (VF8), R67.1
unnamed: CMP-A.5 (LE/HYS), R69.2
unnamed: CMP-B.5 (LE/HYS), R70.2
unnamed: MPEX-A.13 (OUT), R53.1, R71.2
unnamed: MPEX-A.12 (-), R71.1
unnamed: D4.12 (ANODE-CATHODE), MPEX-A.01 (IN1), R72.2, R79.2
unnamed: D6.12 (ANODE-CATHODE), MPEX-A.05 (IN3), R74.2, R77.2
unnamed: D7.12 (ANODE-CATHODE), MPEX-A.07 (IN4), R75.2, R76.2
unnamed: MPEX-B.13 (OUT), R56.1, R80.2
unnamed: MPEX-B.12 (-), R80.1
unnamed: D8.12 (ANODE-CATHODE), MPEX-B.01 (IN1), R81.2, R88.2
unnamed: D9.12 (ANODE-CATHODE), MPEX-B.03 (IN2), R82.2, R87.2
unnamed: D10.12 (ANODE-CATHODE), MPEX-B.05 (IN3), R83.2, R86.2
unnamed: D11.12 (ANODE-CATHODE), MPEX-B.07 (IN4), R84.2, R85.2
unnamed: R90.1, TRIGGER-A.A
unnamed: 2.5VDC.5 (SW), L4.1
unnamed: R89.1, TRIGGER-B.A
unnamed: D5.12 (ANODE-CATHODE), MPEX-A.03 (IN2), R73.2, R78.2
NRUN-2.5: LAB3.084 (NRUN), LEVEL-SHIFT.02 (1A01)
NRUN-3.3: LEVEL-SHIFT.46 (1B01), UC.005 (PB12/TIOA0/TD1)
OLED-DATA0: OLED.17 (D0), UC.032 (PA04/SCK0/SPI1_NPCS0)
OLED-DATA1: OLED.18 (D1), UC.033 (PA05/RTS0/SPI1_NPCS1)
OLED-DATA2: OLED.19 (D2), UC.034 (PA06/CTS0/SPI1_NPCS2)
OLED-DATA3: OLED.20 (D3), UC.035 (PA-7/RXD1/SPI1_NPCS3)
OLED-DATA4: OLED.21 (D4), UC.036 (PA08/TXD1/SPI1_MISO)
OLED-DATA5: OLED.22 (D5), UC.037 (PA09/RXD2/SPI1_MOSI)
OLED-DATA6: OLED.23 (D6), UC.041 (PA10/TXD2/SPI1_SPCK)
OLED-DATA7: OLED.24 (D7), UC.042 (PA11/SPI0_NPCS0)
OLED-DATA8: OLED.25 (D8), UC.043 (PA12/SPI0_NPCS1/MCDA1)
OLED_CS#: OLED.12 (CS#), UC.018 (PB02/TF0/PWM7)
POLARITY-SELECT: GPIO1.1 (IO0), XOR.1 (A), XOR.5 (A)
RAMP-2.5: LAB3.054 (RAMP), LEVEL-SHIFT.25 (2B10)
RAMP-3.3: LEVEL-SHIFT.24 (2A10), UC.080 (PB14/TIOA1/PWM0/ADC0_AD0)
RCO-2.5: LAB3.057 (RCO), UC.006 (PB11/TCLK2/RF1)
RD#: OLED.16 (RD#), UC.020 (PB00/IRQ2/PWM5)
SA00-2.5: LAB3.031 (SA00), LEVEL-SHIFT.39 (1B07)
SA00-3.3: LEVEL-SHIFT.09 (1A07), UC.055 (PA24/PWM6/TCLK4)
SA01-2.5: LAB3.032 (SA01), LEVEL-SHIFT.38 (1B08)
SA01-3.3: LEVEL-SHIFT.10 (1A08), UC.056 (PA25/PWM7/TCLK5)
SA02-2.5: LAB3.033 (SA02), LEVEL-SHIFT.37 (1B09)
SA02-3.3: LEVEL-SHIFT.11 (1A09), UC.057 (PA26/CANRX0)
SA03-2.5: LAB3.034 (SA03), LEVEL-SHIFT.36 (1B10)
SA03-3.3: LEVEL-SHIFT.12 (1A10), UC.058 (PA27/CANTX0)
SA04-2.5: LAB3.035 (SA04), LEVEL-SHIFT.35 (2B01)
SA04-3.3: LEVEL-SHIFT.13 (2A01), UC.062 (PA28/CANRX1/TCLK3)
SA05-2.5: LAB3.036 (SA05), LEVEL-SHIFT.34 (2B02)
SA05-3.3: LEVEL-SHIFT.14 (2A02), UC.063 (PA29/CANTX1/TCLK6)
SA06-2.5: LAB3.037 (SA06), LEVEL-SHIFT.30 (2B05)
SA06-3.3: LEVEL-SHIFT.19 (2A05), UC.064 (PA30/DRXD/TCLK7)
SA07-2.5: LAB3.038 (SA07), LEVEL-SHIFT.29 (2B06)
SA07-3.3: LEVEL-SHIFT.20 (2A06), UC.065 (PA31/DTXD/TCLK8)
SELMAIN-2.5: LAB3.030 (SELMAIN), LEVEL-SHIFT.28 (2B07)
SELMAIN-3.3: LEVEL-SHIFT.21 (2A07), UC.054 (PA23/PWM5/IRQ1)
SELTAIL-2.5: LAB3.043 (SELTAIL), LEVEL-SHIFT.27 (2B08)
SELTAIL-3.3: LEVEL-SHIFT.22 (2A08), UC.053 (PA22/PWM3/IRQ0)
SHUTDOWN#: R10.1, R45.1, UC.030 (SHDW)
SHUTDOWN#-MINUS-5V: +-5VDC.2 (SHDN#), GPIO3.12 (IO7)
SHUTDOWN#-PLUS-5V: +-5VDC.4 (SHDN2#), GPIO3.11 (IO6)
TRIGGER-A: FFA.4 (Q), R64.1, R90.2, UC.007 (PB10/TCLK1/RK1)
TRIGGER-B: FFB.4 (Q), R68.1, R89.2, UC.008 (PB09/TCLK0/TK1)
TRIGGER-CLEAR: FFA.6 (CLEAR#), FFB.6 (CLEAR#), GPIO1.2 (IO1)
TWCK: 4DACS.14 (SCL), GPIO1.6 (TWCK), GPIO2.14 (TWCK), GPIO3.14 (TWCK), MPEX.01 (SCL), R48.1, RTC.6 (SCL), UC.022 (PA01/TWCK/ADC1_ADTRG)
TWD: 4DACS.13 (SDA), GPIO1.7 (TWD), GPIO2.15 (TWD), GPIO3.15 (TWD), MPEX.03 (SDA), R49.1, RTC.7 (SDA), UC.021 (PA00/TWD/ADC0_ADTRG)
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

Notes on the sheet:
RC=10ms
i2c address=1001100
LM3670-2.5V
i2c address = 0110000
100k -> 75mV hysteresis
omit for 2mV hysteresis
[-64,64]
[-16,16]
[-8,8]
[-2,2]
[0.875,1.625]
i2c address = 0011111
[-0.75,0.75]
[0.5,2]
i2c address = 0100000
i2c address = 0100010

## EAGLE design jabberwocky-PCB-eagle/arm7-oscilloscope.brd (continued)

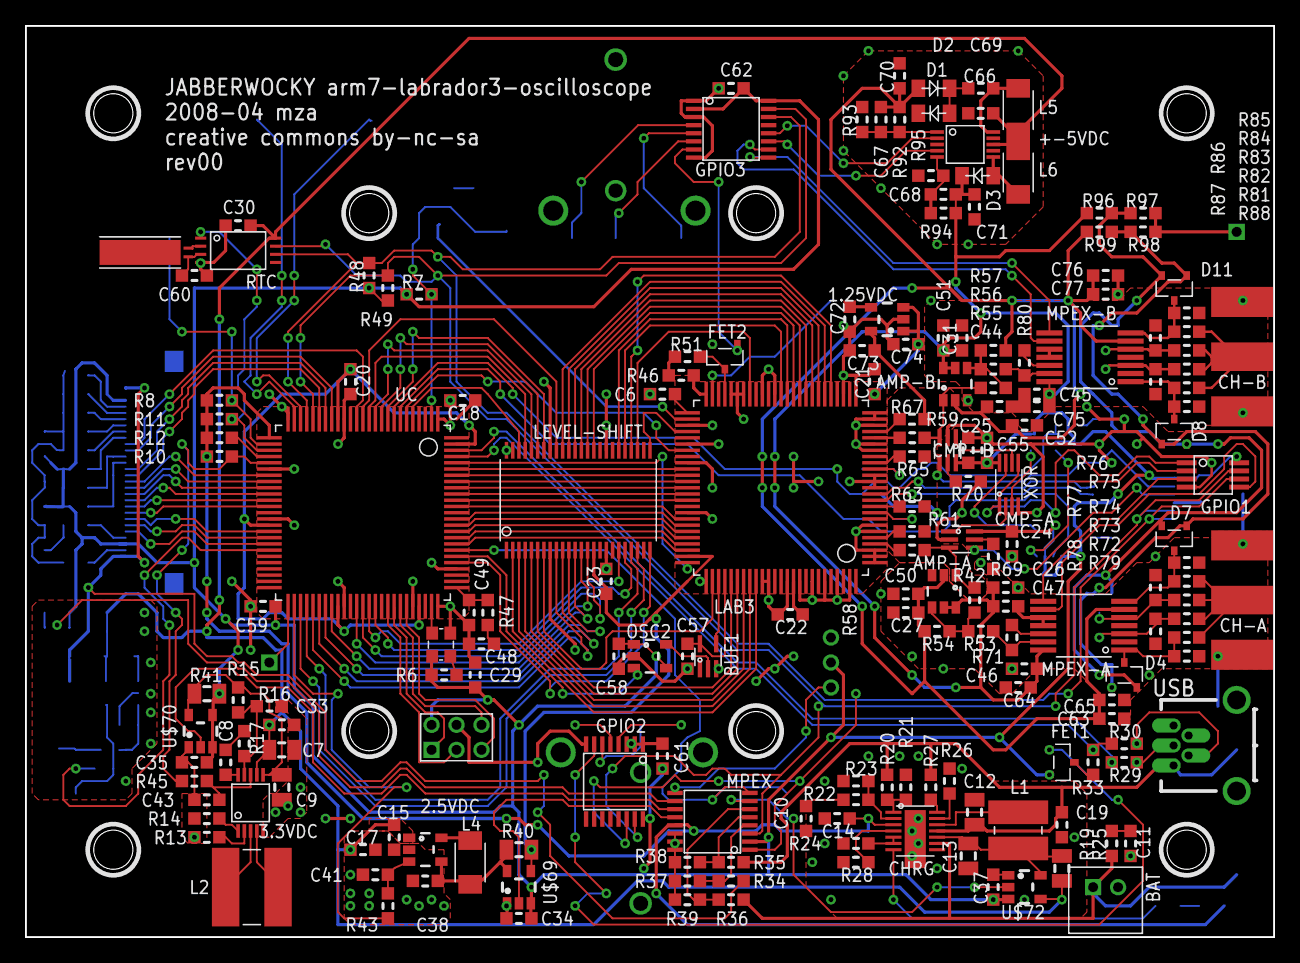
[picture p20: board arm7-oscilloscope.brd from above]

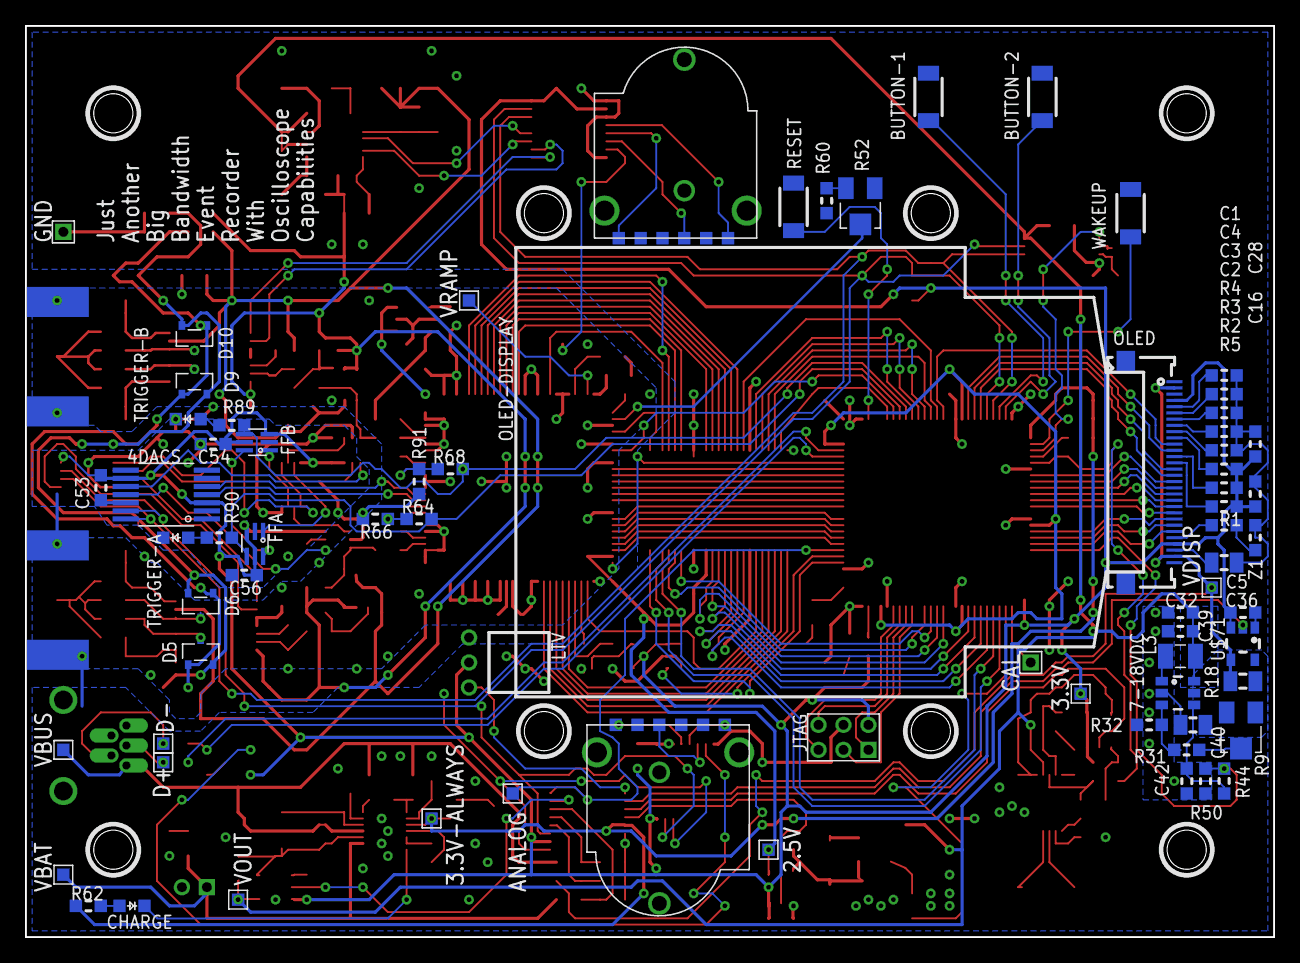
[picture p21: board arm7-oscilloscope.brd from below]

Board: 2 copper layers, 100.0 x 73.0 mm, 266 parts (79 on the bottom side), 222 nets.

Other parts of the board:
OLED-DISPLAY: OLED-DISPLAY-OUTLINE-UNFURLED
U$6, U$37, U$59, U$77, U$176, U$177, U$178, U$179: MOUNTING-HOLE-4-40-SHCS

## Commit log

2015-08-12 well, google code is going readonly soon, so I guess I'd better finally post this stuff
    [arm-usb-tiny.cfg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]
2015-08-17 made 3d model of PCB and designed case around it (solidworks2014); added timing diagram scans; added images of first data acquired (hexdump) and first trace displayed (jpeg); updated eagle files to x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
    [arm7-oscilloscope.brd, arm7-oscilloscope.ods, arm7-oscilloscope.sch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]
2015-08-17 added a couple of images of the device in operation; added lowres images

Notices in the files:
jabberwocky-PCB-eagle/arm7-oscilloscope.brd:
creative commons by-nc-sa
